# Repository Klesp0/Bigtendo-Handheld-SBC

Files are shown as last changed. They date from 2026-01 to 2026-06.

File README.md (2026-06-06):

# Bigtendo Handheld SBC

A portable gaming console built from scratch around a Raspberry Pi 5 and an Adafruit Feather RP2040. It runs RetroPie for retro game emulation and original games written in Pygame and Godot, all controlled with analog joysticks and physical buttons through a custom USB-HID gamepad interface. The whole thing lives inside a 3D-printed two-part enclosure designed in Fusion 360.

The console combines a Raspberry Pi 5 running RetroPie with a separate microcontroller (Feather RP2040) that handles all gamepad input. The RP2040 reads two analog joysticks and 17 physical buttons, applies calibration and deadzone logic, and presents itself to the Pi as a standard USB-HID gamepad, meaning every piece of software on the Pi (EmulationStation, RetroArch, pygame, Godot) sees it as a normal controller with zero extra configuration.

Audio goes through an I2S DAC (Adafruit PCM5122) into a PAM8403 Class D stereo amplifier driving two small cavity speakers. Power comes from a Suptronics X1201 UPS HAT with dual 18650 Li-Ion cells.

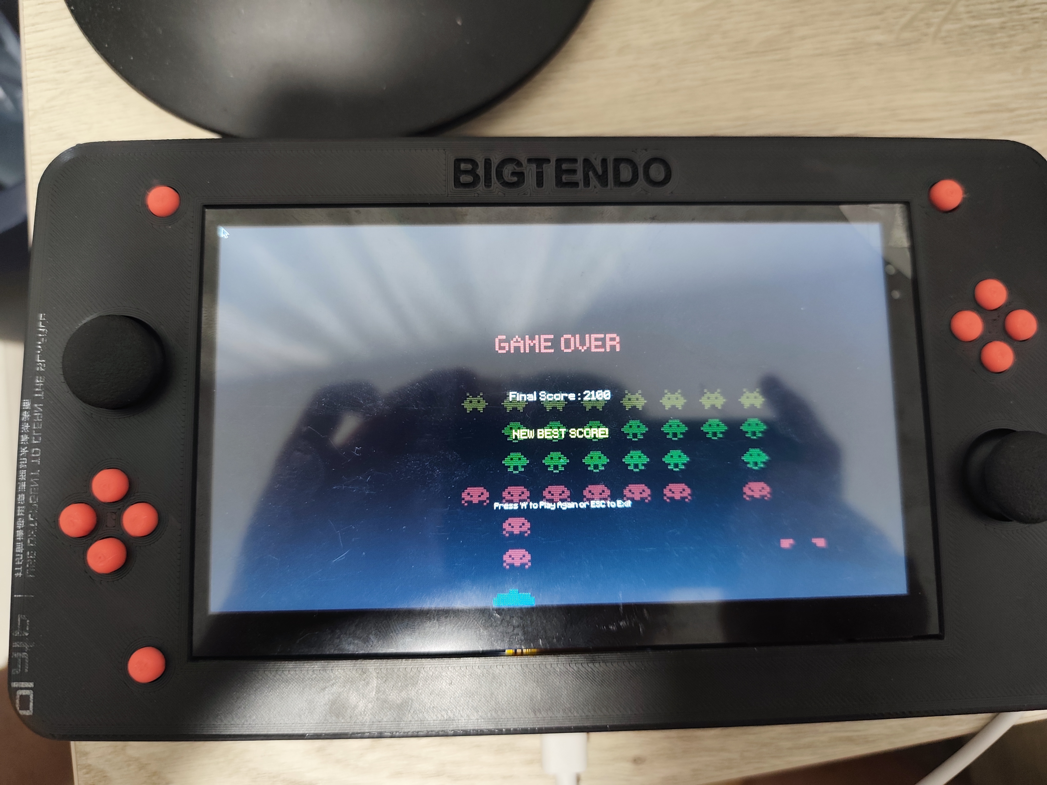
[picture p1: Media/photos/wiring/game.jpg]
Bigtendo Console


---

### Why We Built It

We wanted to understand how a real consumer device works, from the PCB-level electronics to the operating system configuration and to the mechanical design. Buying a kit or following a tutorial wouldn't teach us that. Every part of this console forced us to learn something new: I2S audio protocols, USB-HID protocol, device tree overlays, 3D printing tolerances, soldering, and a lot of debugging.

We are currently designing a custom PCB to combine the audio DAC, amplifier, controller logic, and battery management onto a single board, replacing both the perfboard wiring and the UPS HAT, significantly reducing the internal complexity, size and making the whole build cheaper than buying a standalone UPS module.

### How to Use It

The console boots directly into EmulationStation, RetroPie's game browser. Use the D-pad and A/B buttons to navigate and launch games. Retro games run through RetroArch emulators, and our custom pygame and Godot titles launch the same way through the Ports section, everything is accessible from one menu. The gamepad shows up as a standard USB controller, so it also works if you plug the Feather into any PC. Pick it up to play some games, or use it as a hands-on platform for learning embedded systems, hardware design, Linux configuration, and game development.

---

## Photos

| | |
|:---:|:---:|
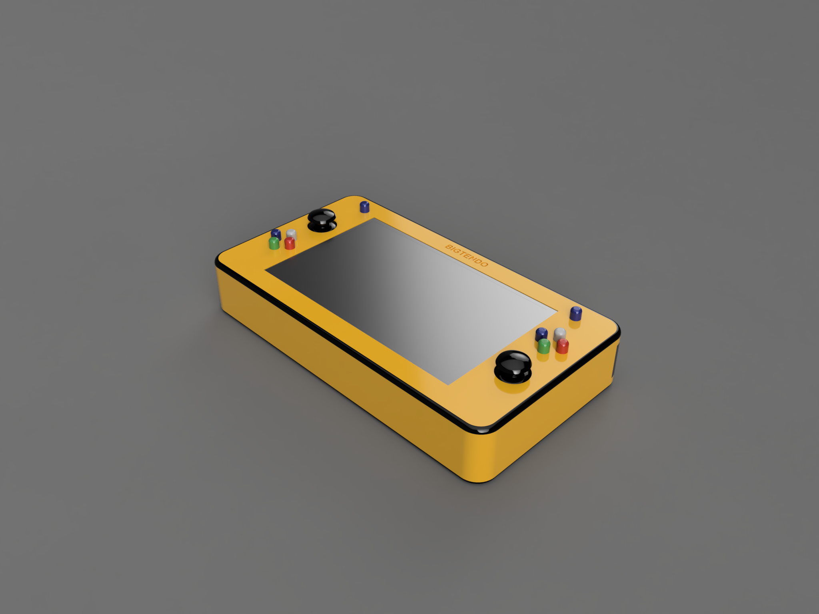
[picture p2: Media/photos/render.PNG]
render
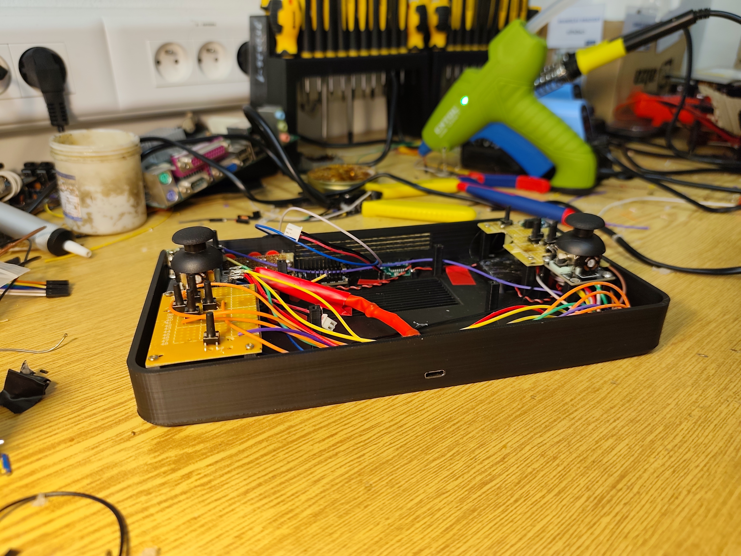
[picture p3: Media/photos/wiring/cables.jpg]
cables
|  |  |
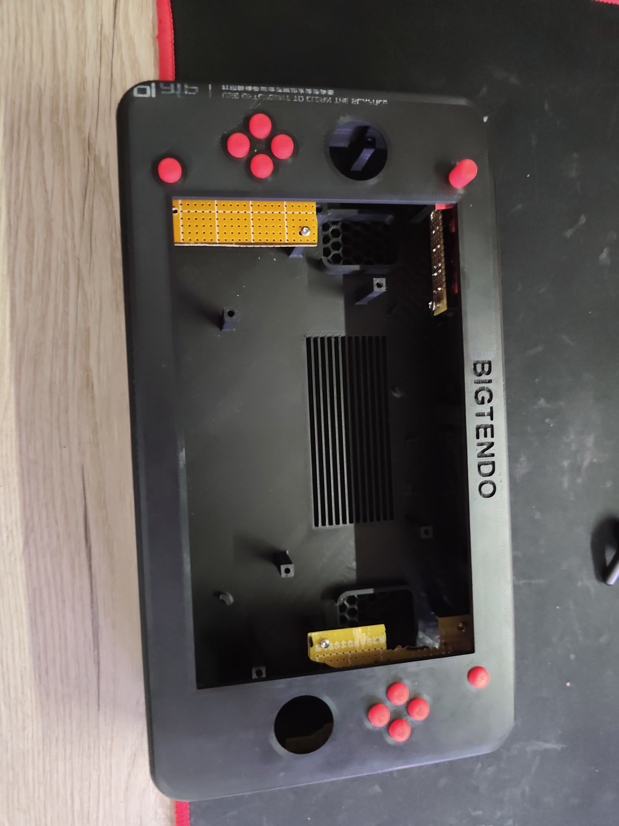
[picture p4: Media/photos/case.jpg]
top
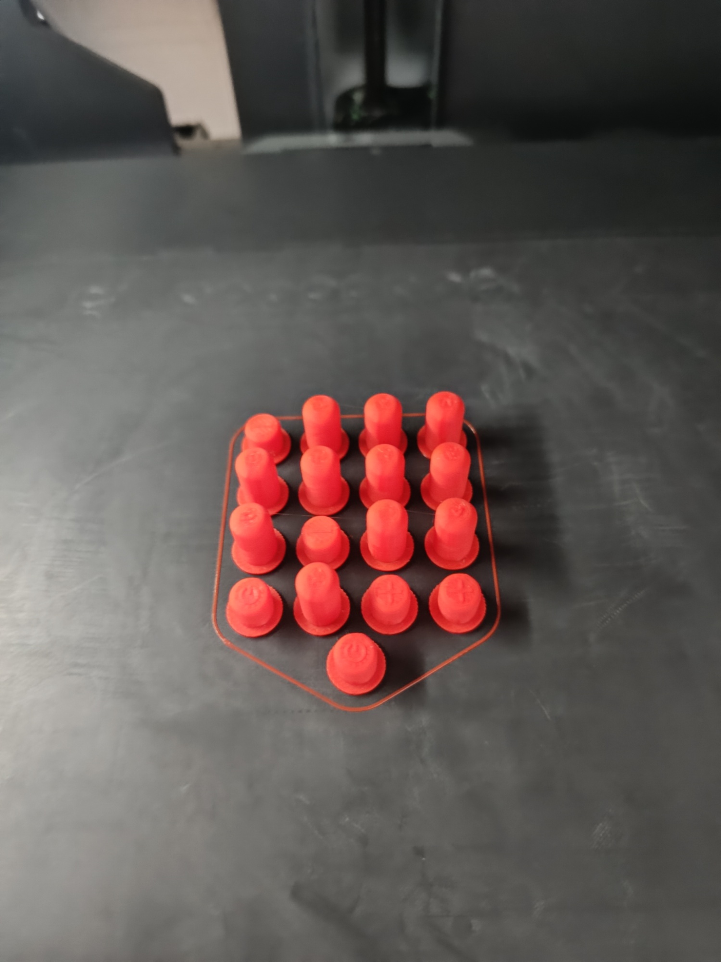
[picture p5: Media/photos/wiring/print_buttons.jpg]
buttons
|  |  |
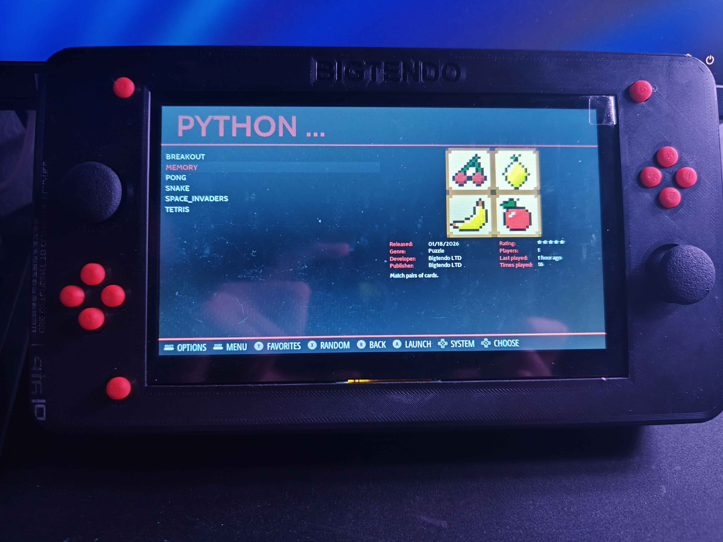
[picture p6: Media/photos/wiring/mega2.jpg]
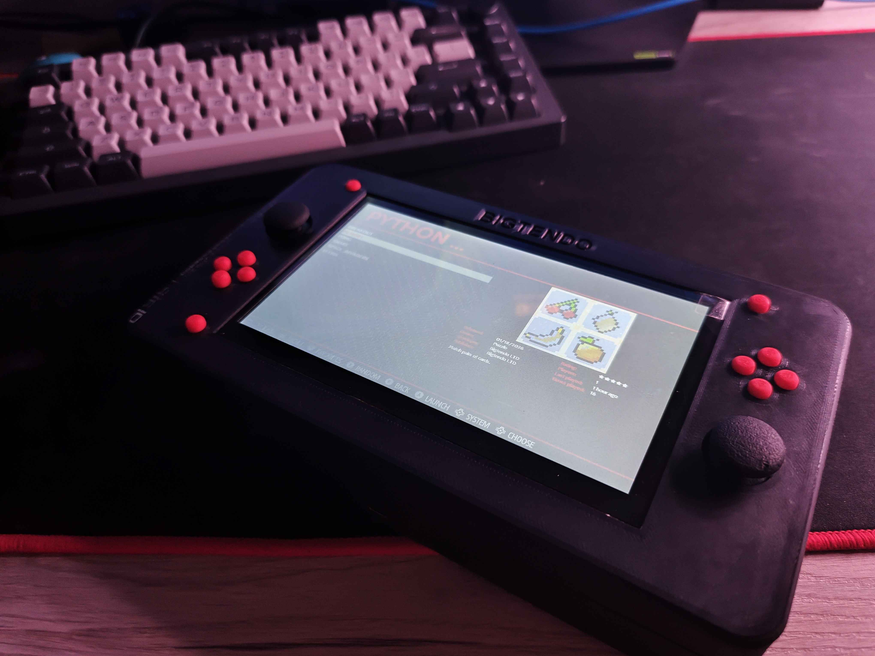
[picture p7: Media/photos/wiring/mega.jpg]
|  |  |

---

## Hardware

| Component | Details |
|---|---|
| **Compute** | Raspberry Pi 5 (8GB RAM), RetroPie OS |
| **Controller** | Adafruit Feather RP2040, USB-HID gamepad with auto-calibration, deadzone, axis inversion/swap |
| **Inputs** | 2x analog joysticks, 17x tactile buttons (D-pad, A/B/X/Y, Start/Select/Home, shoulders) |
| **Audio** | Adafruit PCM5122 I2S DAC, PAM8403 Class D amp, 2x 2030 cavity speakers (8 ohm, 2W) |
| **Power** | Suptronics X1201 UPS HAT + 2x 18650 Li-Ion cells |
| **Display** | 7" HDMI touchscreen (1024x600) |
| **Enclosure** | 3D-printed PLA, ~245 x 135 x 45mm, Bambu Lab X1 Carbon |

---

## Repository Structure

Each folder has its own README with more detail.

```
├── Design/          ← CAD models (.f3d, .step, .stl), assets (icons, sprites, sounds)
├── Firmware/        ← Feather RP2040 CircuitPython controller firmware
├── Games/           ← Pygame and Godot titles
├── Docs/            ← Build guide, wiring guide, pin mapping
├── Media/           ← Build photos and screenshots
├── BOM.csv          ← Bill of materials with purchase links
└── README.md        ← You are here
```

---

## How to Build

Full instructions in **[Docs/build_guide.md](Docs/build_guide)** and **[Docs/wiring_guide.md](Docs/wiring_guide)**. Print the case, flash the Feather, wire everything, configure the Pi, assemble, and play.

---

## Built By

- **[@Klesp0](https://github.com/Klesp0)** - Hardware, CAD, electronics, firmware, audio, assembly
- **[@lukas513](https://github.com/lukas513)** - Games (Pygame and Godot), co-designed enclosure
- **[@A-Kosec](https://github.com/A-Kosec)** - Pygame games, game design, visual assets, configuring retropie

---

## License

[GNU General Public License v3.0](LICENSE)

---

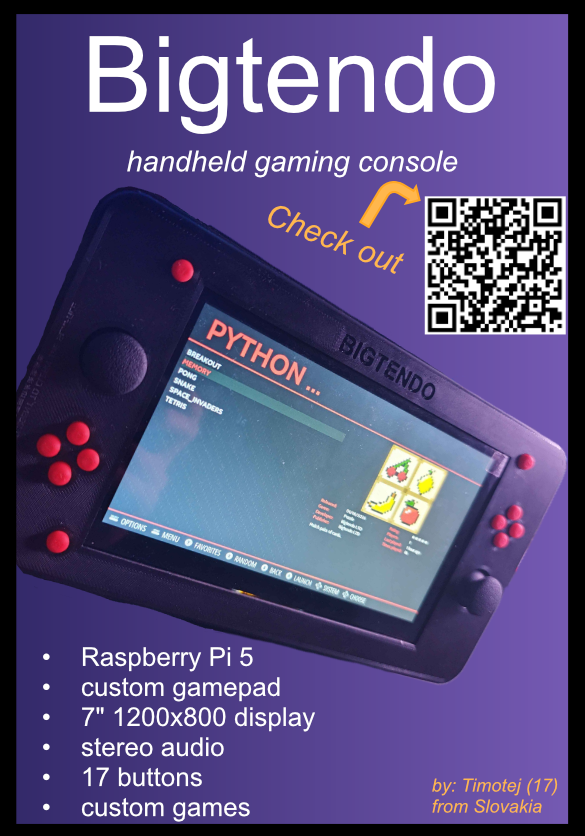
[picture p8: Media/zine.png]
zine


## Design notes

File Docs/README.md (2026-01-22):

# Documentation

Documentation for the Bigtendo handheld SBC console.

* **build-guide/** - Build guide with photos
* **wiring-guide/** - Wiring instructions
* **PCB\_schematics/** - Design files for the upcoming integrated V2 board

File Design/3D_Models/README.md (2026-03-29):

.f3z - original Fusion files

.3mf - files for printing. If you have bambulab you can just change your 3d printer and print with my settings.

.step -  neutral 3d file

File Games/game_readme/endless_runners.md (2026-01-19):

# 🏃 Endless Runner

## Overview
Chrome Dino-style endless runner with desert theme. Jump and slide to avoid obstacles while running at increasing speed.

## Gameplay
- **Objective**: Run as far as possible without hitting obstacles
- **Controls**: 
  - **SPACE / A button**: Jump
  - **DOWN / Crouch button**: Slide
- **Scoring**: Distance traveled (meters)
- **Difficulty**: Speed increases over time

## Features
- ✅ Procedural obstacle generation
- ✅ Running, jumping, sliding animations
- ✅ Parallax scrolling background
- ✅ Collectible coins
- ✅ Power-ups (magnet, shield)
- ✅ Day/night cycle
- ✅ High score tracking

## Technical Details
- **Languages**: GDScript
- **Scenes**: 
  - Main.tscn (game world)
  - Player.gd (character controller)
  - ObstacleSpawner.gd (procedural generation)

## Assets Required
- Player sprites: run (4 frames), jump, slide
- Obstacles: cactus (3 variants), bird, rock
- Backgrounds: sky, mountains (2 layers), ground
- Collectibles: coin (3 frame animation)
- Power-ups: magnet, shield icons

## Development Time
**Estimated**: 4-5 hours
- Player movement: 1h
- Obstacle spawning: 1.5h
- Collision detection: 1h
- UI & polish: 1.5h

## Testing Checklist
- [ ] Jump feels responsive
- [ ] Slide animation works
- [ ] Obstacles spawn at correct intervals
- [ ] Collision detection accurate
- [ ] Score increments properly
- [ ] Game over screen shows
- [ ] High score saves

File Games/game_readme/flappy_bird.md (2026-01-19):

# 🐦 Flappy Bird

## Overview
Classic Flappy Bird clone with pixel art style. Tap to flap through pipes.

## Gameplay
- **Objective**: Pass through as many pipes as possible
- **Controls**: 
  - **SPACE / A button**: Flap wings
- **Scoring**: 1 point per pipe passed
- **Difficulty**: Fixed pipe speed, tight gaps

## Features
- ✅ Simple one-button control
- ✅ Smooth gravity physics
- ✅ Procedural pipe generation
- ✅ Parallax clouds
- ✅ Wing flapping animation
- ✅ Medal system (bronze/silver/gold)
- ✅ High score

## Technical Details
- **Engine**: Godot 4.3
- **Physics**: Custom gravity (980 units/s²)
- **Key Scripts**:
  - Bird.gd (physics + animation)
  - Pipe.gd (scrolling + collision)
  - GameManager.gd (scoring + game state)

## Assets Required
- Bird: 3 frame flapping animation
- Pipes: top and bottom segments
- Background: sky gradient, clouds, ground
- UI: medal icons, game over screen

## Development Time
**Estimated**: 4-5 hours
- Bird physics: 1h
- Pipe spawning: 1.5h
- Collision: 1h
- UI & polish: 1.5h

## Difficulty Tuning
```gdscript
const GRAVITY = 980.0        # Adjust for difficulty
const JUMP_VELOCITY = -600.0 # Lower = harder
const PIPE_SPEED = 200.0     # Higher = harder
const PIPE_GAP = 200.0       # Smaller = harder
```

## Testing Checklist
- [ ] Bird flaps on input
- [ ] Gravity feels natural
- [ ] Pipes scroll smoothly
- [ ] Gap size is fair
- [ ] Collision detection accurate
- [ ] Score increments correctly
- [ ] Game over works
- [ ] Restart works

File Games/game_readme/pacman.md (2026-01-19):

# 👻 Pac-Man

## Overview
Classic Pac-Man maze game with 4 ghosts (Blinky, Pinky, Inky, Clyde). Eat pellets, avoid ghosts, use power-ups.

## Gameplay
- **Objective**: Eat all pellets without getting caught by ghosts
- **Controls**: 
  - **Arrow keys / D-Pad**: Move Pac-Man
- **Scoring**: 
  - Small pellet: 10 points
  - Power pellet: 50 points
  - Ghost: 200/400/800/1600 points (combo)
  - Fruit: 100-1000 points
- **Lives**: 3

## Features
- ✅ Classic maze layout
- ✅ 4 ghosts with unique AI
- ✅ Power pellets (eat ghosts)
- ✅ Fruit bonus items
- ✅ Ghost house behavior
- ✅ Scatter/Chase mode switching
- ✅ Warp tunnels
- ✅ Death/respawn animation
- ✅ Level progression

## Technical Details
- **Engine**: Godot 4.3
- **Grid-based movement**: 32x32 tiles
- **AI Algorithms**:
  - **Blinky**: Chases Pac-Man directly
  - **Pinky**: Targets 4 tiles ahead of Pac-Man
  - **Inky**: Uses Blinky's position + Pac-Man
  - **Clyde**: Chases until close, then scatters
- **Pathfinding**: BFS (Breadth-First Search)

## Ghost AI States
1. **Scatter**: Each ghost targets corner
2. **Chase**: Hunt Pac-Man with unique strategy
3. **Frightened**: Run away (after power pellet)
4. **Eyes**: Return to ghost house after eaten

## Assets Required
- Pac-Man: 8 directional sprites, death animation
- Ghosts: 4 colors x 4 directions, frightened state, eyes
- Maze: tileset for walls, pellets, power pellets
- Fruit: cherry, strawberry, orange, apple
- UI: lives indicator, score, ready text

## Development Time
**Estimated**: 7-9 hours
- Maze & movement: 2h
- Ghost AI (basic): 3h
- Ghost AI (advanced): 2h
- Power pellets & scoring: 1h
- UI & polish: 1h

## Testing Checklist
- [ ] Pac-Man moves in 4 directions
- [ ] Can't move through walls
- [ ] Eats pellets correctly
- [ ] Ghosts chase properly
- [ ] Power pellets work
- [ ] Eating ghosts gives points
- [ ] Warp tunnels work
- [ ] Level completes when all pellets eaten
- [ ] Lives system works
- [ ] Game over at 0 lives

## Known Issues
- Ghost AI can get stuck in corners (workaround: add random scatter)

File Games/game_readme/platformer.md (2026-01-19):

# 🎮 Platformer

## Overview
2D platformer inspired by Super Mario. Jump, run, collect coins, defeat enemies, reach the flag.

## Gameplay
- **Objective**: Reach the end flag
- **Controls**: 
  - **Arrow keys / D-Pad**: Move left/right
  - **SPACE / A button**: Jump
  - **DOWN**: Crouch
- **Mechanics**:
  - Double jump
  - Wall jump
  - Ground pound
  - Enemy stomp
- **Collectibles**: Coins, gems, keys
- **Lives**: 3 (get more at 100 coins)

## Features
- ✅ Physics-based movement
- ✅ Multiple enemy types
- ✅ Destructible blocks
- ✅ Moving platforms
- ✅ Checkpoints
- ✅ Secret areas
- ✅ Boss fight (optional)
- ✅ 3-5 levels

## Technical Details
- **Engine**: Godot 4.3
- **Tilemap**: 32x32 grid
- **Physics**: Godot's built-in CharacterBody2D
- **Key Scripts**:
  - Player.gd (movement, jumps, attacks)
  - Enemy.gd (patrol, chase AI)
  - MovingPlatform.gd (path following)
  - Checkpoint.gd (save progress)

## Player Abilities
```gdscript
const SPEED = 200.0
const JUMP_VELOCITY = -500.0
const DOUBLE_JUMP_VELOCITY = -400.0
const GRAVITY = 980.0
const WALL_SLIDE_SPEED = 50.0
```

## Enemy Types
- **Slime**: Patrols back and forth
- **Flying**: Sine wave pattern
- **Spikes**: Stationary hazard
- **Boss**: Multi-phase fight (if time permits)

## Assets Required
- Player: idle, walk (4 frames), run (4 frames), jump, fall, crouch, hurt, death
- Enemies: slime (2 frames), fly (2 frames), spike
- Tiles: ground, platforms, walls, spikes, coins, gems, key, door, flag
- Backgrounds: sky, clouds, mountains, trees
- Effects: jump dust, landing dust, hit effect

## Development Time
**Estimated**: 6-8 hours
- Player movement: 2h
- Tilemap & level design: 2h
- Enemy AI: 2h
- Collectibles & checkpoints: 1h
- Polish & sound: 1h

## Level Design Tips
- Start easy, increase difficulty gradually
- Teach mechanics before requiring them
- Place checkpoints after difficult sections
- Hide secrets off the main path
- Add visual hints (coins leading to platforms)

## Testing Checklist
- [ ] Jump feels good (height, gravity)
- [ ] Wall jump works
- [ ] Double jump works
- [ ] Enemy collisions work
- [ ] Stomp kills enemies
- [ ] Touching enemy hurts player
- [ ] Coins collected properly
- [ ] Checkpoints save progress
- [ ] Death respawns at checkpoint
- [ ] Can reach flag

## Known Issues
- Player can get stuck in walls if moving too fast (add collision buffer)

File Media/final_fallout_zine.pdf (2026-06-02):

# Bigtendo

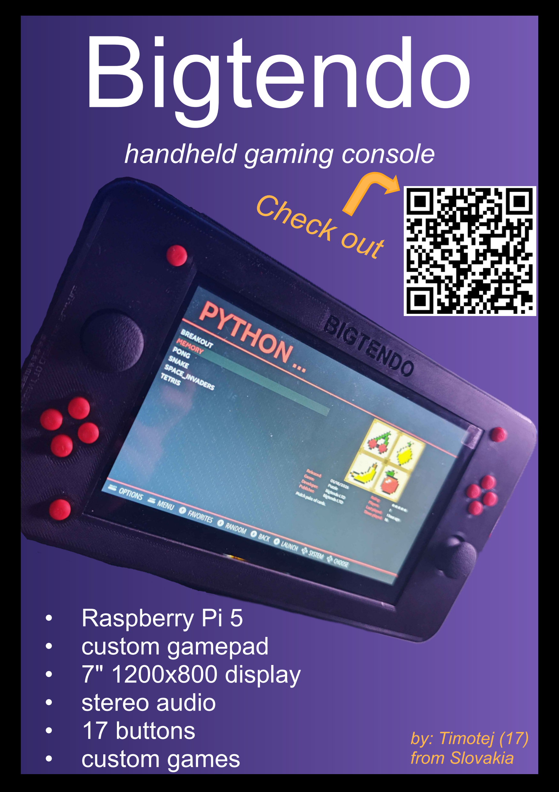
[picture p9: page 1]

## Check out

- Raspberry Pi 5
- custom gamepad
- 7" 1200x800 display
- stereo audio
- 17 buttons
- custom games

by: Timotej (17)
from Slovakia

handheld gaming console

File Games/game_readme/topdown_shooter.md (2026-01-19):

# 🔫 Top-Down Shooter

## Overview
Hotline Miami-style top-down shooter. Aim with mouse/joystick, shoot enemies, clear rooms.

## Gameplay
- **Objective**: Clear all enemies in each room
- **Controls**: 
  - **Arrow keys / Left stick**: Move (8-way)
  - **Mouse / Right stick**: Aim
  - **SPACE / A button**: Shoot
  - **R**: Reload
- **Weapons**: Pistol, Rifle, Shotgun
- **Health**: 100 HP
- **Scoring**: Kills, accuracy, time bonus

## Features
- ✅ 8-way movement
- ✅ Mouse/joystick aiming
- ✅ 3 weapon types
- ✅ Enemy AI (patrol, chase, shoot)
- ✅ Line of sight system
- ✅ Destructible objects
- ✅ Multiple rooms/levels
- ✅ Ammo management
- ✅ Health pickups
- ✅ Blood effects

## Technical Details
- **Engine**: Godot 4.3
- **View**: Top-down orthogonal
- **Key Scripts**:
  - Player.gd (movement, aiming, shooting)
  - Enemy.gd (AI state machine)
  - Weapon.gd (fire rate, damage, ammo)
  - Bullet.gd (projectile physics)

## Weapon Stats
```gdscript
# Pistol
damage = 20
fire_rate = 0.3
ammo_capacity = 12
reload_time = 1.5

# Rifle
damage = 15
fire_rate = 0.1
ammo_capacity = 30
reload_time = 2.0

# Shotgun
damage = 10 (x6 pellets)
fire_rate = 0.8
ammo_capacity = 6
reload_time = 2.5
```

## Enemy AI States
1. **Patrol**: Walk along waypoints
2. **Alert**: Player spotted, move to last seen position
3. **Chase**: Follow player
4. **Attack**: Stop and shoot at player
5. **Cover**: Hide behind obstacles when low health

## Assets Required
- Player: idle (4 directions), walk (4 directions x 2 frames)
- Enemies: soldier, robot, turret
- Weapons: pistol, rifle, shotgun sprites
- Bullets: small projectile, muzzle flash
- Environment: walls, crates, doors, barrels
- Effects: blood splatter, explosion, smoke
- UI: health bar, ammo counter, crosshair

## Development Time
**Estimated**: 8-10 hours
- Player controller: 2h
- Enemy AI: 3h
- Weapons & shooting: 2h
- Level design: 2h
- Polish: 1h

## Level Design
- Start with tutorial room (1 enemy)
- Gradually increase enemy count
- Mix enemy types for variety
- Place cover strategically
- Add health/ammo pickups after tough fights

## Testing Checklist
- [ ] Mouse aiming smooth
- [ ] Joystick aiming works
- [ ] Shooting feels responsive
- [ ] Enemies chase properly
- [ ] Line of sight works
- [ ] Cover system works
- [ ] Ammo system works
- [ ] Reload works
- [ ] Health system works
- [ ] Death/respawn works

## Known Issues
- AI can get stuck on corners (add navigation mesh)

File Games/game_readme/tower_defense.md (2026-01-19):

# 🗼 Tower Defense

## Overview
Classic tower defense. Build towers, upgrade them, stop enemy waves from reaching your base.

## Gameplay
- **Objective**: Survive all waves without losing all lives
- **Controls**: 
  - **Mouse / D-Pad**: Select tower, place on map
  - **Click tower**: Upgrade or sell
- **Resources**: 
  - **Money**: Build/upgrade towers
  - **Lives**: Lose when enemies reach end
- **Towers**: Basic, Cannon, Laser, Ice
- **Enemies**: Basic, Fast, Tank, Flying

## Features
- ✅ 4 tower types (3 upgrade levels each)
- ✅ 4 enemy types
- ✅ Path-based enemy movement
- ✅ Tower range indicators
- ✅ Upgrade system
- ✅ Sell towers (50% refund)
- ✅ 10-15 waves
- ✅ Speed up button (2x)
- ✅ Pause menu

## Technical Details
- **Engine**: Godot 4.3
- **Pathfinding**: Predefined path (not A*)
- **Key Scripts**:
  - Tower.gd (targeting, shooting, upgrading)
  - Enemy.gd (path following, health)
  - WaveManager.gd (spawn timing, difficulty scaling)
  - GameManager.gd (money, lives, win/lose)

## Tower Stats

### Basic Tower
- **Cost**: 100
- **Damage**: 10 → 20 → 30
- **Fire Rate**: 1.0s → 0.8s → 0.6s
- **Range**: 150 → 170 → 200

### Cannon Tower
- **Cost**: 200
- **Damage**: 50 → 80 → 120 (AOE)
- **Fire Rate**: 2.0s → 1.5s → 1.0s
- **Range**: 180 → 200 → 220

### Laser Tower
- **Cost**: 250
- **Damage**: 5 (continuous)
- **Fire Rate**: 0.1s
- **Range**: 200 → 220 → 250

### Ice Tower
- **Cost**: 150
- **Damage**: 5 → 10 → 15
- **Slow**: 50% → 60% → 70%
- **Range**: 120 → 140 → 160

## Enemy Types
- **Basic**: 100 HP, 50 speed, 10 reward
- **Fast**: 60 HP, 100 speed, 15 reward
- **Tank**: 300 HP, 30 speed, 30 reward
- **Flying**: 80 HP, 70 speed, 20 reward (immune to ground towers)

## Wave Scaling
```gdscript
func calculate_wave_difficulty(wave_num):
    enemy_count = 5 + wave_num * 2
    enemy_health_multiplier = 1.0 + wave_num * 0.1
    enemy_speed_multiplier = 1.0 + wave_num * 0.05
```

## Assets Required
- Towers: 4 types x 3 levels = 12 sprites
- Tower projectiles: bullet, cannonball, laser beam, ice shard
- Enemies: 4 types x 2 frames = 8 sprites
- Map tiles: grass, path
- UI: tower menu, upgrade panel, money/lives display
- Effects: explosion (3 frames), ice effect

## Development Time
**Estimated**: 10-12 hours
- Tower system: 3h
- Enemy pathfinding: 2h
- Wave manager: 2h
- Upgrade system: 2h
- UI & map: 2h
- Balancing: 1h

## Balancing Tips
- Early waves should be easy (teach mechanics)
- Introduce 1 new enemy type every 3 waves
- Boss waves at 5, 10, 15
- Money rewards should allow 1 tower per wave
- Player should need 3-4 upgraded towers to win

## Testing Checklist
- [ ] Towers place correctly
- [ ] Range indicators show
- [ ] Towers shoot enemies in range
- [ ] Targeting works (closest, strongest, etc.)
- [ ] Upgrades apply correctly
- [ ] Selling works
- [ ] Enemies follow path
- [ ] Money system works
- [ ] Lives decrease when enemy reaches end
- [ ] All waves completable
- [ ] Win condition works
- [ ] Lose condition works

## Known Issues
- Towers can shoot through obstacles (add line-of-sight check)

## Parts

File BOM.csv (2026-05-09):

Component | Qty | Unit Price (EUR) | Total (EUR) | Supplier | Link | Total (EUR) | 296.46
Raspberry Pi 5 - 8GB RAM | 1 | 128.96 | 128.96 | RPishop.cz | https://rpishop.cz/raspberry-pi-5/6498-raspberry-pi-5-8gb-ram.html
Suptronics X1201 UPS Shield for RPi 5 | 1 | 39.45 | 39.45 | RPishop.cz | https://rpishop.cz/523690/suptronics-x1201-ups-shield-pro-raspberry-pi-5/
PremiumCord Flexi HDMI Typ A (F) - micro HDMI Typ D (M) adapter | 1 | 3.66 | 3.66 | RPishop.cz | https://rpishop.cz/499888/premiumcord-flexi-adapter-hdmi-typ-a-samice-micro-hdmi-typ-d-samec-pro-ohebne-zapojeni/
Waveshare DIY HDMI flat cable 0.1m | 1 | 2.02 | 2.02 | RPishop.cz | https://rpishop.cz/diy-hdmi/3012-diy-hdmi-plochy-kabel-10-cm.html
HDMI connector for DIY cable - right angle (up) male | 1 | 5.31 | 5.31 | RPishop.cz | https://rpishop.cz/diy-hdmi/3017-hdmi-koncovka-pro-diy-hdmi-kabel-pravy-uhel-prava-samec.html
micro HDMI connector for DIY cable - right angle (up) | 1 | 5.31 | 5.31 | RPishop.cz | https://rpishop.cz/diy-hdmi/2855-adafruit-micro-hdmi-adapter-pro-diy-hdmi-kabel-pravouhly-konektor-pravy-ohyb.html
7 inch 1024x600 TFT display for RPi HDMI touch | 1 | 43.00 | 43.00 | LaskaKit | https://www.laskakit.cz/en/7--1024x600-tft-displej-pro-raspberry-pi--hdmi--dotykovy/
Raspberry Pi 5 Active Cooler | 1 | 6.15 | 6.15 | Elecom.sk | https://www.elecom.sk/raspberry-pi-5-active-cooler-2/
Adafruit Feather RP2040 | 1 | 15.50 | 15.50 | Elecom.sk | https://www.elecom.sk/adafruit-feather-rp2040/
Adafruit PCM5122 I2S DAC with Line Level Output | 1 | 10.60 | 10.60 | Elecom.sk | https://www.elecom.sk/adafruit-pcm5122-i2s-dac-with-line-level-output-hw--i2c-or-spi/
2030 Cavity Speaker 8Ohm 2W 2PIN PH1.25 | 2 | 2.23 | 4.46 | Elecom.sk | https://www.elecom.sk/2030-cavity-speaker-type-b--8-2w--high-quality-sound--compact-size--2pin-ph1-25-connector/
Kingston Canvas Select Plus microSDXC 128GB Class 10 UHS-I | 1 | 13.79 | 13.79 | Alza.sk | https://www.alza.sk/kingston-canvas-select-plus-micro-sdxc-128gb-class-10-uhs-i-sd-adapter-d5689872.htm
Perfboard 5cm x 7cm | 3 | 0.80 | 2.40 | Techfun.sk | https://techfun.sk/produkt/univerzalny-plosny-spoj-obojstranny/?attribute_pa_rozmery=5-cm-x-7-cm
PAM8403 stereo 2x3W mini amplifier | 1 | 0.65 | 0.65 | Techfun.sk | https://techfun.sk/produkt/pam8403-stereo-2x3w-mini-zosilnovac/
Tactile buttons 6x6x13mm (pack of 50) | 1 | 2.50 | 2.50 | Techfun.sk | https://techfun.sk/produkt/tlacidla-50-kusov-6x6x13-mm/
Tactile buttons 6x6x6mm (pack of 50) | 1 | 2.50 | 2.50 | Techfun.sk | https://techfun.sk/produkt/tlacidla-50-kusov-6x6x6-mm/
XH2.54 connector with cable 2P male+female | 3 | 0.40 | 1.20 | Techfun.sk | https://techfun.sk/produkt/konektor-s-kablikom-xh2-54-rozne-typy/
Joysticks | 2 | 0.75 | 1.50 | Techfun.sk | https://techfun.sk/produkt/joystick-2-osi-analogovy-vystup/
18650 battery EVE INR18650-26ME 2600mAh 15A | 2 | 3.75 | 7.50 | Techfun.sk | https://techfun.sk/produkt/18650-bateria-eve-inr18650-25p-2500mah-8c-20a/
Electrical tape | 1 | 0.80 | 0.80 | Techfun.sk | https://techfun.sk/produkt/izolacna-elektricka-paska-rozne-farby/
20cm Dupont wire 24awg | 1 | 0.50 | 0.50 | Techfun.sk | https://www.elecom.sk/male-to-male-dupont-line-40-pin-20-cm-24awg/
10cm Dupont wire 24awg | 1 | 1.45 | 1.45 | techfun.sk | https://techfun.sk/produkt/kabliky-40-kusov-10-cm-m-m/
10.9 grade M2-M5 screws kit | 1 | 8.00 | 8.00 | aliexpress | https://www.aliexpress.com/w/wholesale-screws-.html?spm=a2g0o.productlist.search.0

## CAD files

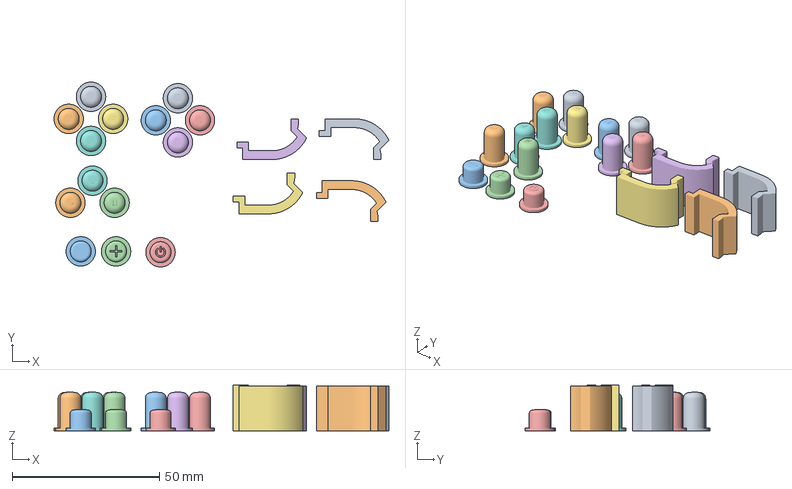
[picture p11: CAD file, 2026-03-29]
Design/3D_Models/.3mf_for_printing/buttons.3mf
113.8 x 62.8 x 15.5 mm
x (1) (1) (1)
x (1) (1)
x (1)
x

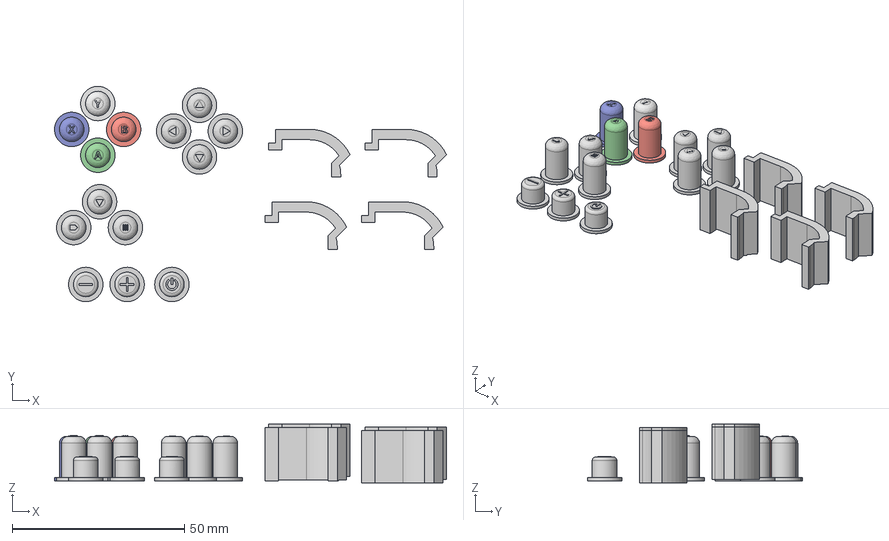
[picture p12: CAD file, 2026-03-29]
Design/3D_Models/.step/Buttons.step
113.8 x 62.5 x 17.0 mm
A, B, Y, X
D-pad
Right Shoulder Buttons x 2
Menu
Volume Down
Volume Up
Power

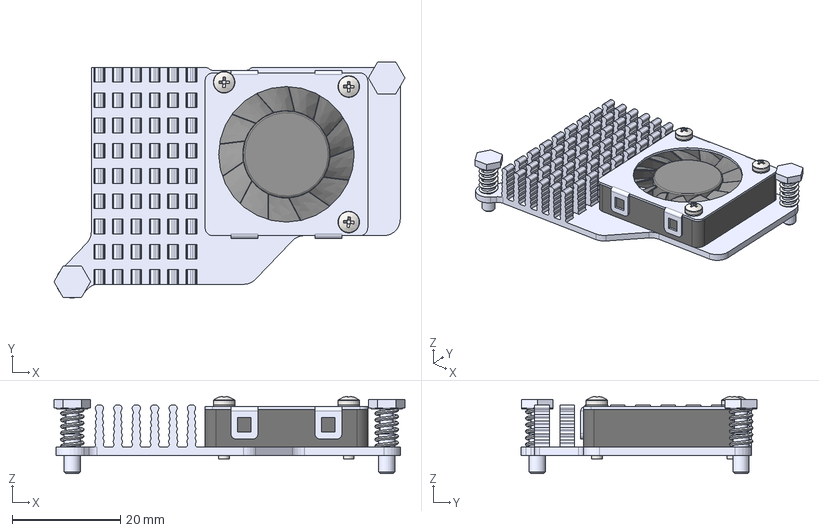
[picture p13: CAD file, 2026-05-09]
Design/3D_Models/component_models/Heatsink+fan RPi-5.step
64.8 x 43.5 x 14.2 mm
Heatsink-fan-base_RPi5
RotorBlades
MotorHouse
fan cover
Bolt_M3 PF x 2
Spring_M2,5 U x 2
pan head cross recess screw_din_DIN EN ISO 7045 - M2 x 10 - Z - 10N x 3
plain washer small grade a_din_Washer DIN 433 - 2 x 3

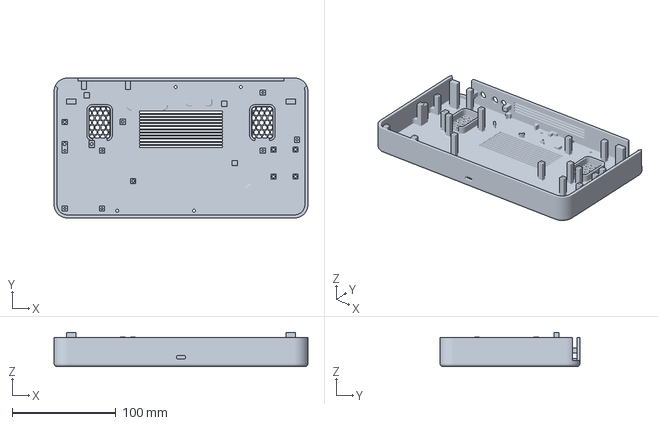
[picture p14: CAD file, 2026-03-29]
Design/3D_Models/.3mf_for_printing/case_lower.3mf
245.0 x 135.0 x 33.0 mm

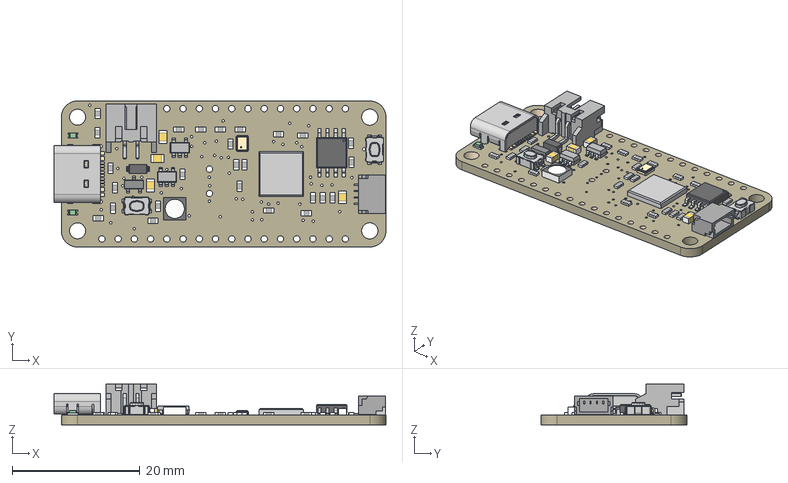
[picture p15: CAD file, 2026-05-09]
Design/3D_Models/component_models/4884 Feather RP2040.step
51.9 x 22.9 x 6.37 mm
Board
10uF x 4
ORANGE x 2
1K x 26
KMR2 x 2
AP2112-3.3
JSTPH
MCP73831T-2ACI/OT
WS2812B3535
2MB Flash
MBR540
DMG341
USB Type C
RP2040_QFN56
STEMMA_I2C_QT
12MHZ

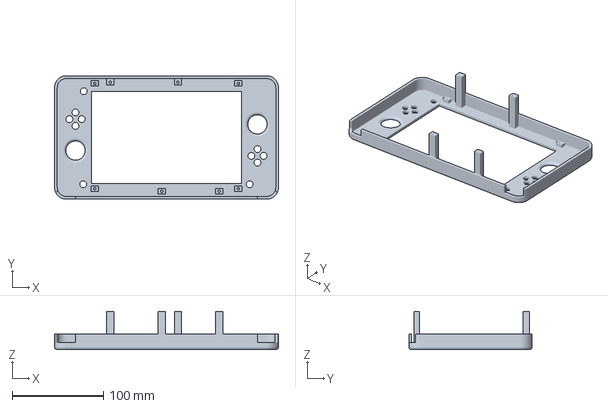
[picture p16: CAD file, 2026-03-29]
Design/3D_Models/.3mf_for_printing/case_upper.3mf
245.0 x 135.0 x 42.0 mm

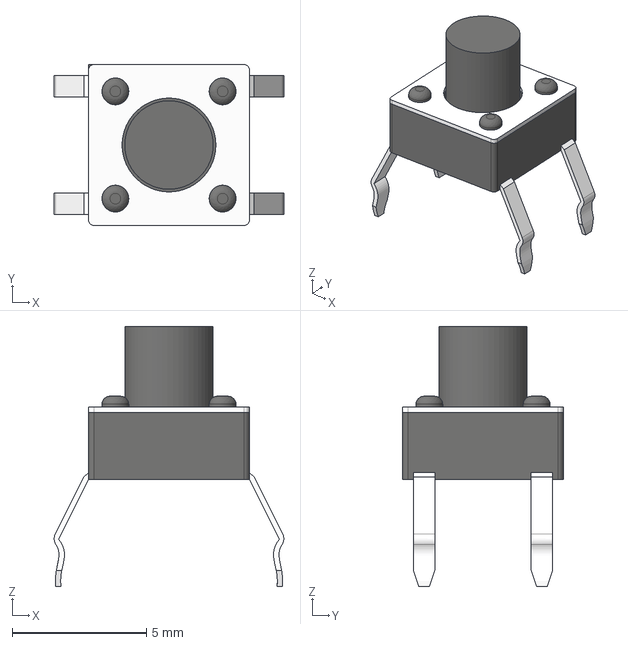
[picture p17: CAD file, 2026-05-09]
Design/3D_Models/component_models/Button 6x6-vyssie.step
8.57 x 6.00 x 9.70 mm

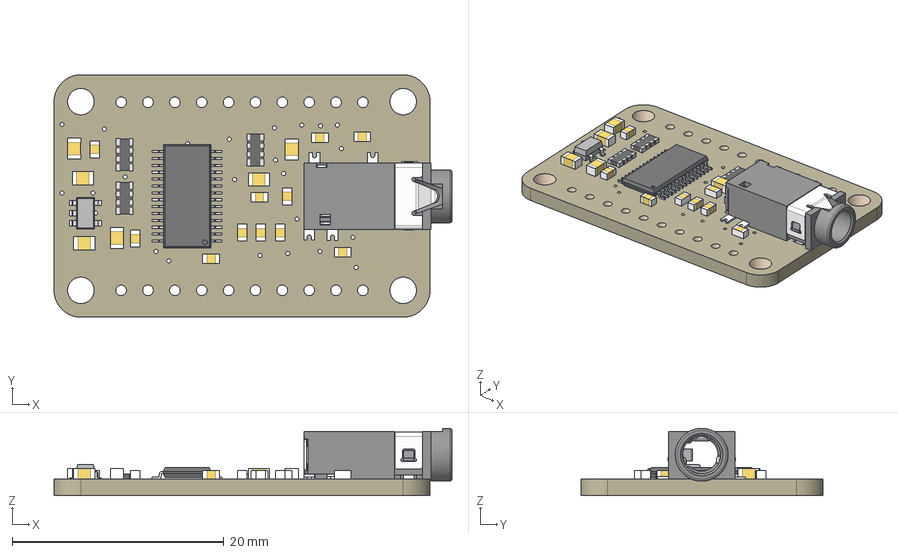
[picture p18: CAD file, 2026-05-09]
Design/3D_Models/component_models/Adafruit PCM5122 I2S DAC.step
37.6 x 22.9 x 6.37 mm
Board
2.2uF x 11
AP2127K-3.3
10uF x 6
TRRS_2SWITCH_PJ332A
PCM5122
10K x 3

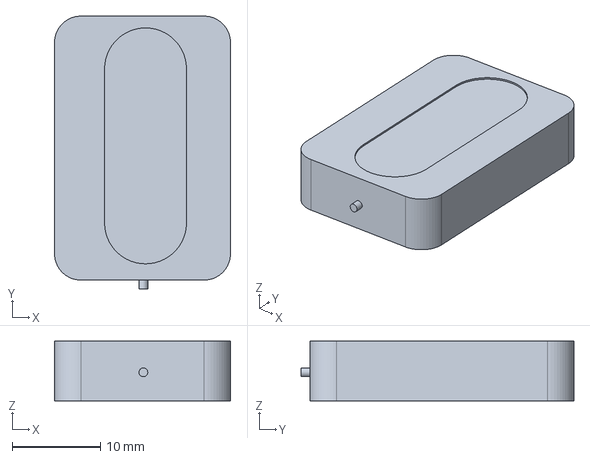
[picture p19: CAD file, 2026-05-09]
Design/3D_Models/component_models/speaker.step
20.0 x 31.0 x 6.80 mm

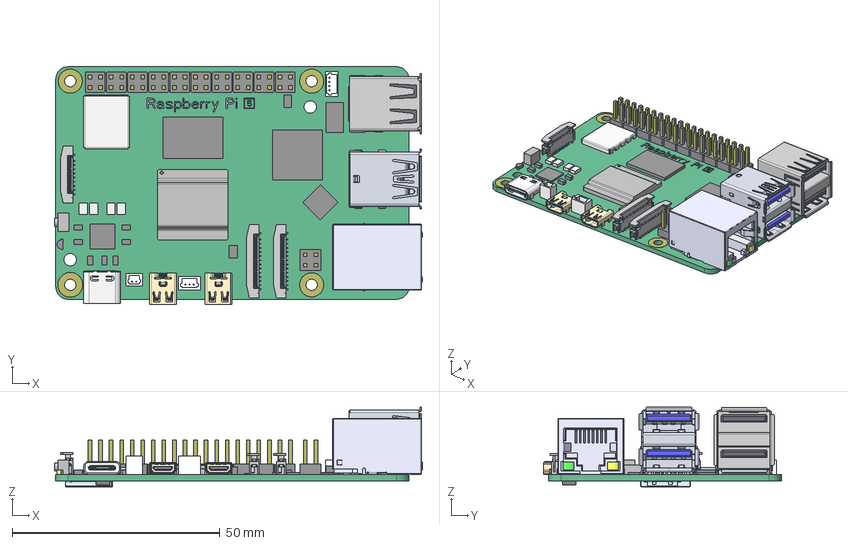
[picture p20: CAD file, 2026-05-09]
Design/3D_Models/component_models/raspberry_pi_5.step
88.5 x 57.2 x 19.2 mm
CONNECTOR
GPIO-HEADER
GROUND-1426
GROUND-1427
GROUND-1428
GROUND-1429
PCB
RAM
CPU
CHIP-1454
CHIP-1455
CHIP-1456
CHIP-1457
PMIC
POE_GEOMETRY
PWR-CONNECTOR
RP1
UART
XB-U224-08XN-1XR61
GIGABIT_ETHERNET_PORT__RPI4MODE
IMPORTED6-42380_1
IMPORTED9-52935_1
IMPORTED10-72927_1
IMPORTED7-187449_1
IMPORTED5-264500_1
IMPORTED3-272013_1
IMPORTED2-275127_1
N-396500_1
IMPORTED4-497392_1
IMPORTED8-498029_1
FEMALE_USB_TYPE_C_CONNECTOR__RP
FEMALE_MICRO_HDMI_CONNECTOR__RP x 2
2X_USB3_0_PORTS__RPI4MODELB_ANY
IR_1
CYPRESS_CYW43455_WIRELESS_MODUL
SWITCH-1559

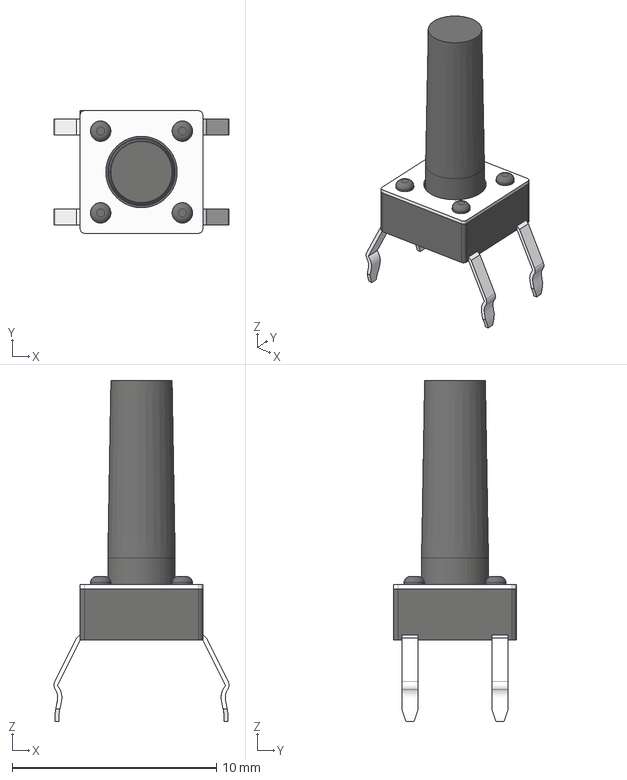
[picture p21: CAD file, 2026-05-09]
Design/3D_Models/component_models/Button 6x6x13.step
8.57 x 6.00 x 16.7 mm

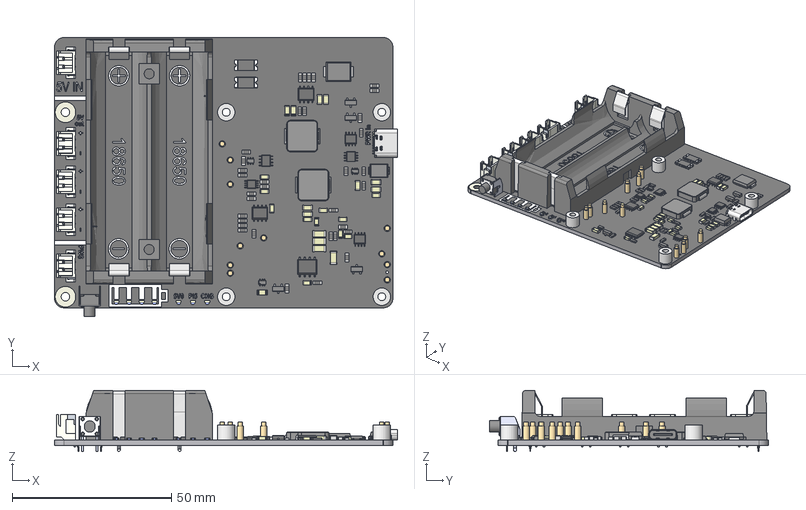
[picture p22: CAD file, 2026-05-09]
Design/3D_Models/component_models/Geekworm X1201 UPS Shield for RPi 5.step
107.8 x 87.7 x 19.3 mm
back side
front side
pads
PCB
pogo pin (20)
pogo pin (19)
pogo pin (18)
pogo pin (17)
pogo pin (16)
pogo pin (15)
pogo pin (14)
pogo pin (13)
pogo pin (12)
pogo pin (11)
pogo pin (10)
chip
chip_1
inductor (1)
inductor
fuse p lf (1)
fuse p lf
chip3 (2)
chip3 (1)
chip3
chip (2)
chip (1)
chip (1)_1
chip (1)_2
chip (1)_3
chip (2)_1
chip (1)_4
chip_2
resistor3 (5)
resistor3 (6)
resistor3 (6)_1
resistor3 (9)
resistor3 (8)
resistor3 (7)
resistor3 (17)
resistor3 (16)
resistor3 (19)
resistor3 (19)_1
resistor3 (18)
resistor3 (18)_1
resistor3 (17)_1
resistor3 (16)_1
resistor3 (15)
resistor3 (14)
resistor3 (16)_2
resistor3 (15)_1
resistor3 (14)_1
resistor3 (13)
resistor3 (12)
resistor3 (11)
resistor3 (10)
resistor3 (10)_1
resistor3 (9)_1
resistor3 (8)_1
resistor3 (7)_1
resistor3 (6)_2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

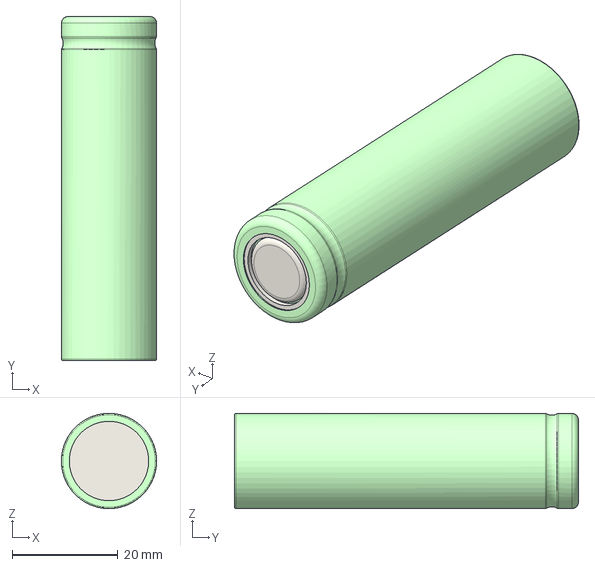
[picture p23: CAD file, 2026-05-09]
Design/3D_Models/component_models/Battery.step
18.0 x 65.0 x 18.0 mm

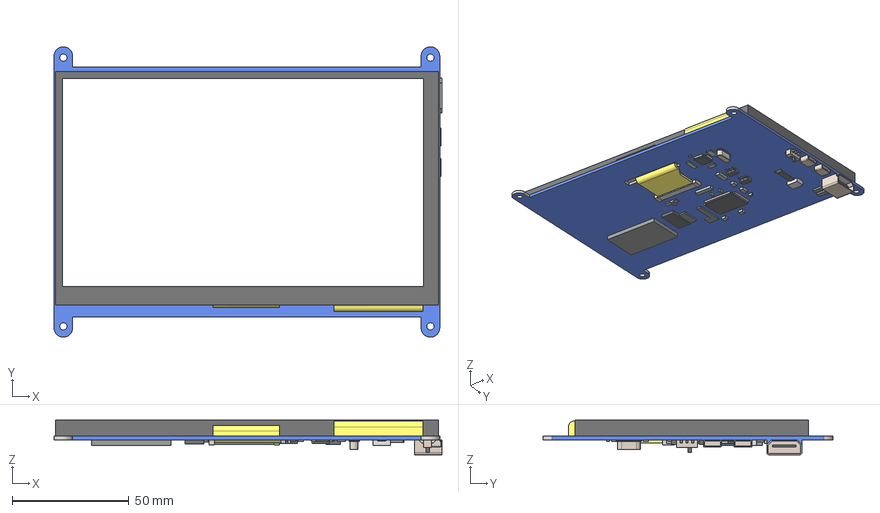
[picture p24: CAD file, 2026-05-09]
Design/3D_Models/component_models/display.step
166.1 x 124.3 x 14.9 mm

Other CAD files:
Design/3D_Models/.step/case_lower.step
Design/3D_Models/.step/case_upper.step
Design/3D_Models/component_models/amplfier PAM8403 3W.step
Design/3D_Models/component_models/USB Connector Type C female.STEP
Design/3D_Models/.f3z/Buttons.f3z
Design/3D_Models/.f3z/case_upper.f3z
Design/3D_Models/.stl/buttons.stl
Design/3D_Models/.stl/case_lower.stl
Design/3D_Models/.stl/case_upper.stl
Design/3D_Models/component_models/joystick.step

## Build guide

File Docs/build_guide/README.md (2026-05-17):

# Build Guide

Step-by-step instructions for building the Bigtendo console. Read the [Wiring Guide](Docs\wiring_guide\README.md) alongside this for detailed connection tables.

---

## Step 1 — Gather Parts

Everything you need is in [BOM.csv](BOM.csv) with purchase links. Before ordering, check component dimensions against the [CAD models](Design\3D_Models\component_models) - the enclosure was designed around specific display size.

---

## Step 2 — Print the Enclosure (Settings)

Download the [STL files](\Design\3D_Models\.stl).

>[!NOTE]
>If you have got a bambulab printer just import the [.3mf models](Design\3D_Models\.3mf_for_printing) into BambuStudio.

### Case settings
- **Print both case halves with the flat exterior face down.**

>[!NOTE]
>Upper part doesn't  need supports!

| Setting | Value |
|---|---|
| Material | PLA |
| Layer height | 0.08mm Extra Fine |
| Infill | 20% Gyroid |
| Walls loops | 4  |
| Supports (lower) | tree(auto) Threshold angle |
| Supports (lower) | Top Z distance 0.28mm |
| Bed | Textured PEI |
| Skirt loop (others)|  1 | 
| Print time (lower) | 9h42m |
| Print time (upper) | 4h31m  |
| Filament | 250g total |

### Button settings
- **Button caps print flat side down, no supports.**

| Setting | Value |
|---|---|
| Material | PLA |
| Layer height | 0.08mm Extra Fine |
| Infill | 40% Gyroid |
| Walls loops | 4  |
| Bed | Textured PEI |
| Skirt loop (others)|  1 | 
| Print time | 1h31m |
| Filament | 15g total |

| | |
|:---:|:---:|
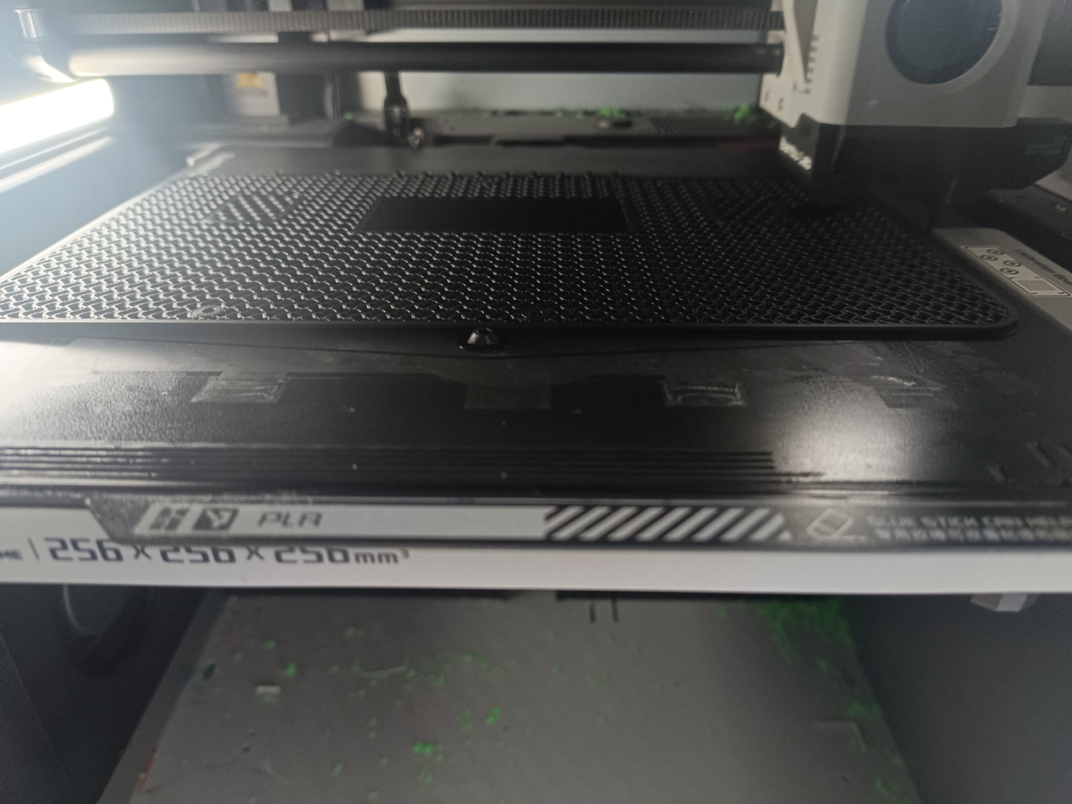
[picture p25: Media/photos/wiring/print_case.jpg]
case
|  | buttons |

---

## Step 3 — Flash the Feather RP2040

1. Download the CircuitPython `.uf2` for the Feather RP2040 from [circuitpython.org](https://circuitpython.org/board/adafruit_feather_rp2040/)
2. Plug the feather into your PC

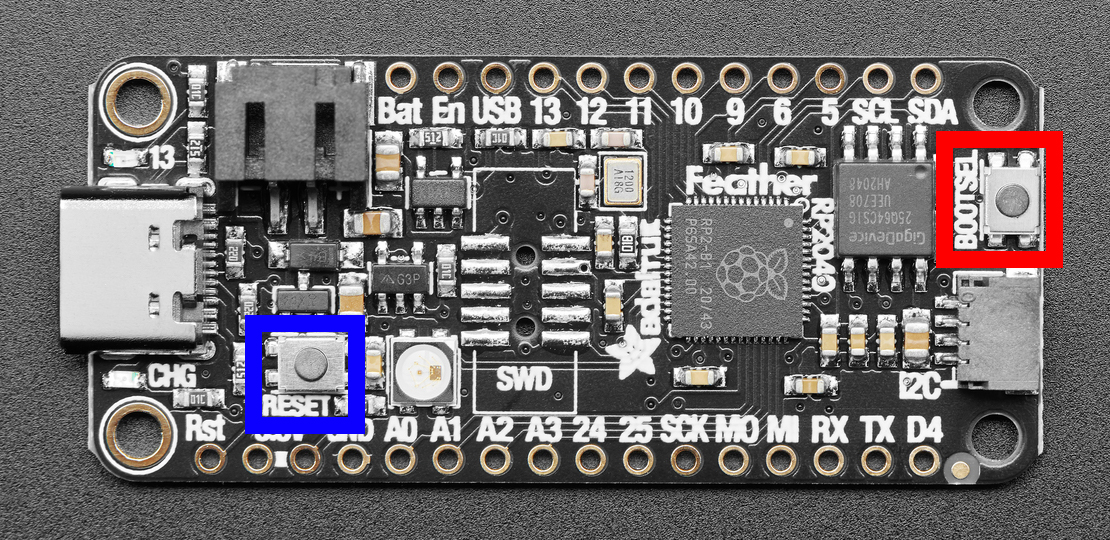
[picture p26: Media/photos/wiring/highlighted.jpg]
button


3. To enter the bootloader, hold down BOOTSEL (highlighted in `red` above), and while continuing to hold it (**`don't let go!`**), press and release the reset button (highlighted in `blue` above). Continue to hold the BOOT/BOOTSEL button until the `RPI-RP2` drive appears!
4. Drag the `.uf2` onto it — the Feather reboots and `CIRCUITPY` appears
5. Copy the firmware files onto `CIRCUITPY`:

```
CIRCUITPY/
├── boot.py
├── code.py
└── lib/
    └── adafruit_hid/
        └── gamepad.py
```

The D13 LED should stay **`blinking`** after reboot. **blinking** = running. **Solid** = error.

---

## Step 4 — Install RetroPie

1. Download the [Raspberry Pi Imager](https://circuitpython.org/board/adafruit_feather_rp2040/) and flash Raspberry Pi OS (64-bit) onto your microSD card.
2. put the cooler onto the raspberry 5 and screw the Raspberry onto the UPS shield
3. 
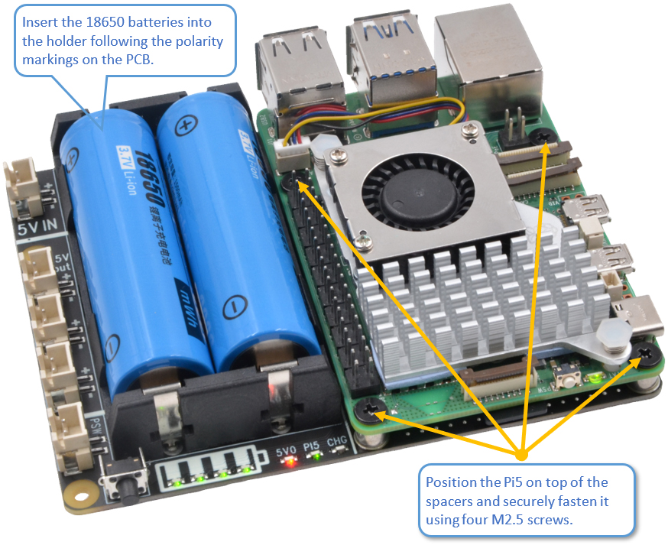
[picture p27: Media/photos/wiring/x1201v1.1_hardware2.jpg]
ups


>[!NOTE]
>Don't inset the batteries just yet

4. Insert the card, connect your monitor, and plug the USB-C power cable into the UPS shield connector. 

> **`don't`** plug it into the Pi 5's own USB-C port

5. After you have everything ready boot into Raspbian and follow this [guide](https://www.youtube.com/watch?v=AaseHnf0k2o), to set up Raspbian and RetroPie on top of it

Watch the video (https://www.youtube.com/watch?v=AaseHnf0k2o)

---

## Step 5 — Load the Games

Download the Roms(games) and continue watching the [guide](https://www.youtube.com/watch?v=AaseHnf0k2o) from 10:15 to add the Roms to the Retropie. 

---

# Step 6 — Set Up the Audio

See the [Wiring Guide](wiring_guide.md) for the full audio schematic and connection tables.

The Pi 5 has no headphone jack, so the PCM5122 DAC is required to convert the digital I2S signal to analog audio. Wire the DAC to the Pi over I2S and I2C (8 wires total), connect the DAC outputs to the PAM8403 inputs, and the amp outputs to the speakers. Make sure MOD2 is pulled to 3.3V.

### Configure the Pi

```
sudo nano /boot/firmware/config.txt
```

Find or add these lines:

```
dtparam=i2c_arm=on        <- Add this line
# dtparam=i2s=on          <- Comment this out or remove it entirely
dtparam=audio=off         <- Disable onboard audio
```

add the DAC overlay at the bottom of the file :

```
dtoverlay=iqaudio-dac
```

> [!IMPORTANT]
> Do **not** leave `dtparam=i2s=on` enabled. RetroPie adds this line, and it causes the kernel to claim GPIO18 (the I2S bit clock) before the `iqaudio-dac` overlay can use it. The DAC will appear in `aplay -l` and respond on I2C, but no audio will actually reach it. Commenting out `dtparam=i2s=on` and letting the overlay manage I2S on its own is the fix.

After rebooting, verify the DAC is detected:

```
aplay -l                         # Should show: card 2: IQaudIODAC
play something on youtube        # Should hear something from both speakers
```

### Make the Config Survive Reboots

RetroPie overwrites the ALSA config on every boot. To prevent this, write the ALSA configuration into the root-level system files where RetroPie can't touch it:

```
sudo nano /etc/alsa/config.txt/bigtendo.conf
```

```
defaults.pcm.card 2
defaults.ctl.card 2
```

This makes the DAC the default audio device system-wide and survives RetroPie reboots.

### If It Doesn't Work

- **No DAC in `aplay -l`:** Run `sudo i2cdetect -y 1` - look for address `4c`.
- **GPIO18 conflict:** Run `dmesg | grep -i i2s` - if you see a conflict, `dtparam=i2s=on` is still enabled. Comment it out.
- **Audio works in Raspbian but not in EmulationStation or games:** The ALSA root-level config above fixes this.

---

## Step 7 — Solder Buttons and Joysticks

See the [Wiring Guide](wiring_guide.md) for the full pin tables.

Each button connects between one Feather GPIO pin and GND, with the internal pull-up resistor enabled in firmware. Getting buttons to sit in exactly the right spots on the perfboard, so they line up with the holes in the 3D-printed enclosure, is the hardest part of the whole assembly.

The technique that worked for me:

1. Tape the button caps tightly in place on the upper shell
2. Put buttons into the caps

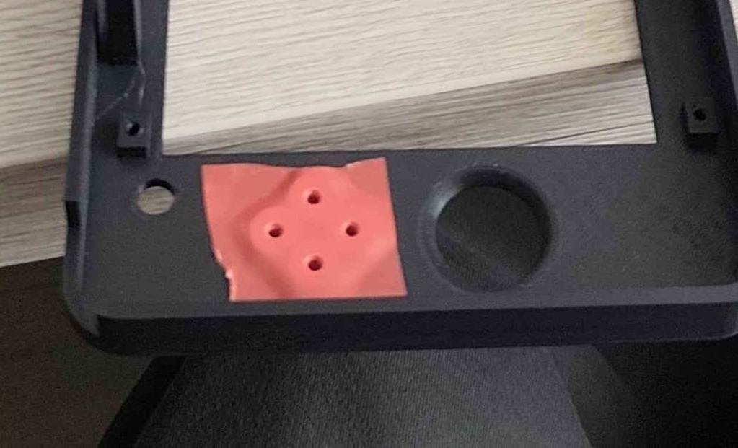
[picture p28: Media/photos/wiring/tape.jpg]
tape


3. Place the upper shell onto the lower half so the buttons touch the perfboard
4. Press the buttons down gently
5. Lift the shell carefully without shifting anything 
6. Mark where their pins land on the perfboard and solder the buttons at those positions
7. Test fit before moving on to the next set

Repeat this for each button. Shoulder buttons don't need precise positioning - they are hot-glued to their pillar anyway, so just solder them wherever they reach and glue them in place.

Each joystick has 5 wires: VCC (3.3V), GND, VRx, VRy, and SW (click). Screw the joysticks into their pillars before soldering the wires. The right joystick is mounted 90° clockwise in the enclosure - don't try to compensate it in wiring, the firmware handles it with `SWAP_JOY1_XY = True` and `INVERT_JOY1_X = True`.

| | |
|:--:|:--:|
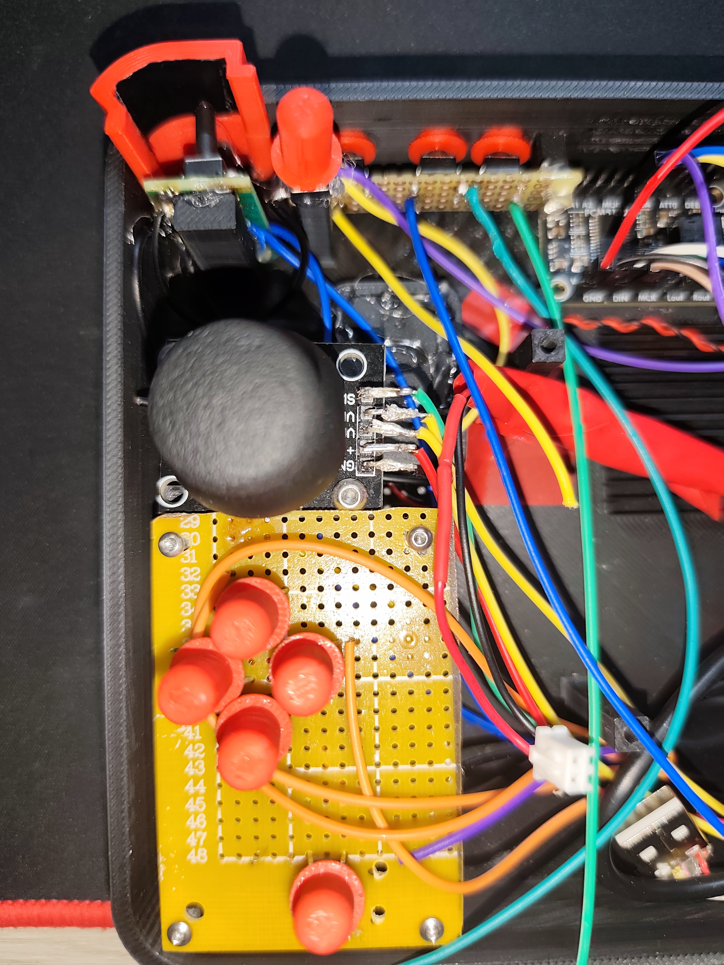
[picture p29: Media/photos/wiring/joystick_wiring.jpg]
joystick wiring
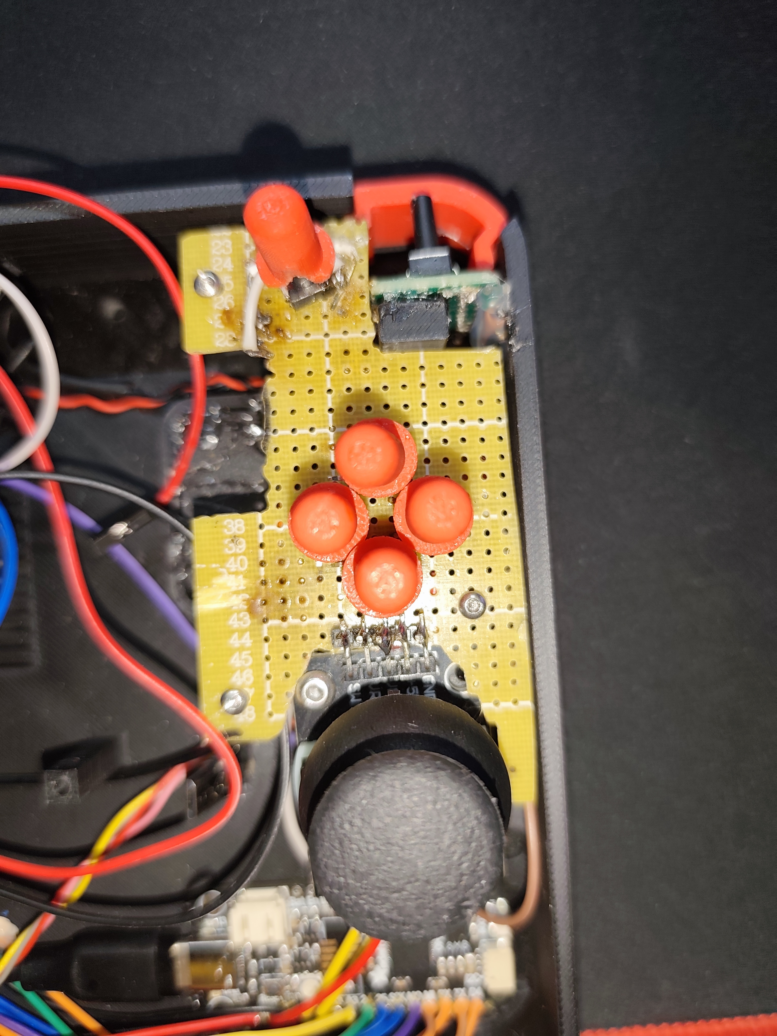
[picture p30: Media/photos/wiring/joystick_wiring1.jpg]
joystick wiring
|  | 

To verify, plug it into any PC and open [hardwaretester.com](https://hardwaretester.com/gamepad) - all 17 buttons and both joystick axes should register.

---

## Step 8 — Final Assembly

### Bottom shell (install in this order)

1. 18650 cells into the battery holders

> [!WARNING]
> Double-check battery polarity before connecting. Reversed polarity can permanently damage the Pi and the UPS shield.

2. PCM5122 DAC and PAM8403 amp into their mounts
3. Speakers on top of the honeycomb grilles
4. screw perfboards and joysticks in position
5. Route all wires flat — pinched wires are the main reason the case won't close

### Top shell

1. Display in its cutout, DSI ribbon cable connected to the Pi
2. Button caps through the shell holes

> [!TIP]
> Tape the back of the UPS shield with electric tape, just to be sage.

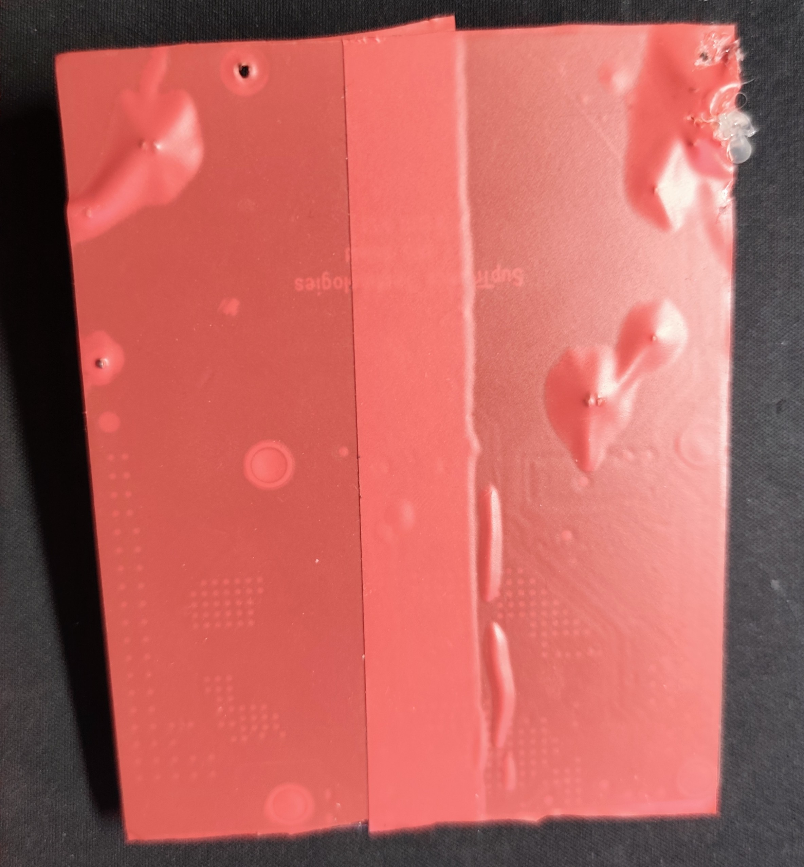
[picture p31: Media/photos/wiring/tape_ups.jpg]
tape


### Close it up

Connect the HDMI ribbon, Feather USB cable, and all remaining wires. Align the two halves and press them together. Screw the 2 halves together. Power on and START PLAYING!

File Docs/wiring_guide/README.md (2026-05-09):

# Wiring Guide

Every wire connection in the Bigtendo console.

## Feather RP2040

Solder all the jumper wires exactly like in the table below - the result should look like the image.

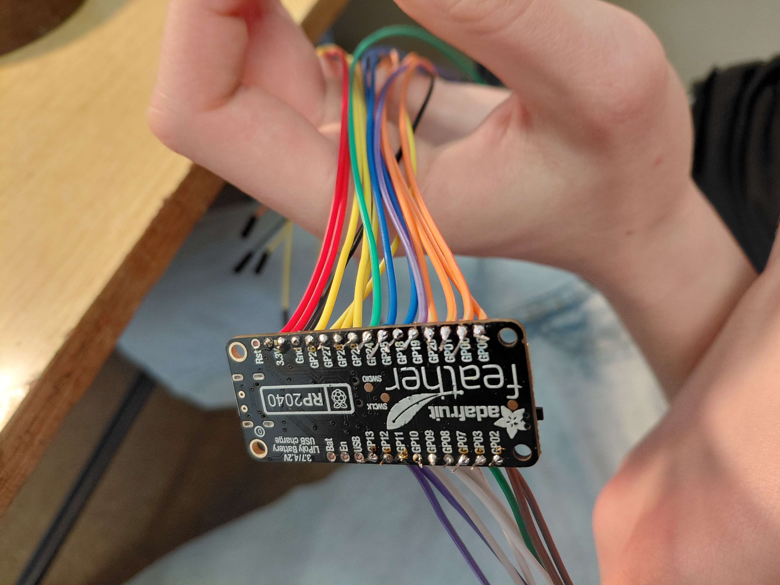
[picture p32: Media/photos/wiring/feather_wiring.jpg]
Feather wiring


| Feather Pins | Wire Color |
|---|---|
| `board.D12` \| `board.D13` \| `board.MOSI` | Purple |
| `board.D11` \| `board.D10` \| `board.D9` \| `board.D6` | White |
| `board.D5` \| `board.D24` | Green |
| `board.SDA` \| `board.SCL` | Brown |
| 3.3V | Red |
| GND | Black |
| `board.A0` \| `board.A1` \| `board.A2` \| `board.A3` | Yellow |
| `board.D25` \| `board.SCK` | Blue |
| `board.MISO` \| `board.RX` \| `board.TX` \| `board.D4` | Orange |

## Buttons

All buttons use the Feather's internal pull-up resistors. One leg connects to the Feather GPIO pin, the other to GND.

### Button Pin Assignments

| Physical Button | CircuitPython Pin | Wire Color |
|---|---|---|
| Left Joystick Click | `board.D5` | Green |
| A | `board.D6` | White |
| B | `board.D9` | White |
| X | `board.D10` | White |
| Y | `board.D11` | White |
| Start | `board.D12` | Purple |
| Select | `board.D13` | Purple |
| Right Joystick Click | `board.D24` | Green |
| Left Trigger (lower) | `board.D25` | Blue |
| Left Trigger (upper) | `board.SCK` | Blue |
| Home | `board.MOSI` | Purple |
| Arrow Down | `board.MISO` | Orange |
| Arrow Up | `board.RX` | Orange |
| Arrow Right | `board.TX` | Orange |
| Right Trigger (upper) | `board.SDA` | Brown |
| Right Trigger (lower) | `board.SCL` | Brown |
| Arrow Left | `board.D4` | Orange |

## Joysticks

Each joystick has 5 pins: VCC (3.3V), GND, VRx (analog X), VRy (analog Y), and SW (click button).

### Right Joystick

| Joystick Pin | Feather Pin | Wire Color |
|---|---|---|
| VRy | `board.A0` | Yellow |
| VRx | `board.A1` | Yellow |
| SW (button) | `board.D5` | Green |
| VCC | 3.3V | Red |
| GND | GND | Black |

### Left Joystick

| Joystick Pin | Feather Pin | Wire Color |
|---|---|---|
| VRy | `board.A2` | Yellow |
| VRx | `board.A3` | Yellow |
| SW (button) | `board.D24` | Green |
| VCC | 3.3V | Red |
| GND | GND | Black |

## Audio Schematic

**Signal path:** Pi 5 -> PCM5122 I2S DAC -> PAM8403 Stereo Class D Amplifier -> Speakers

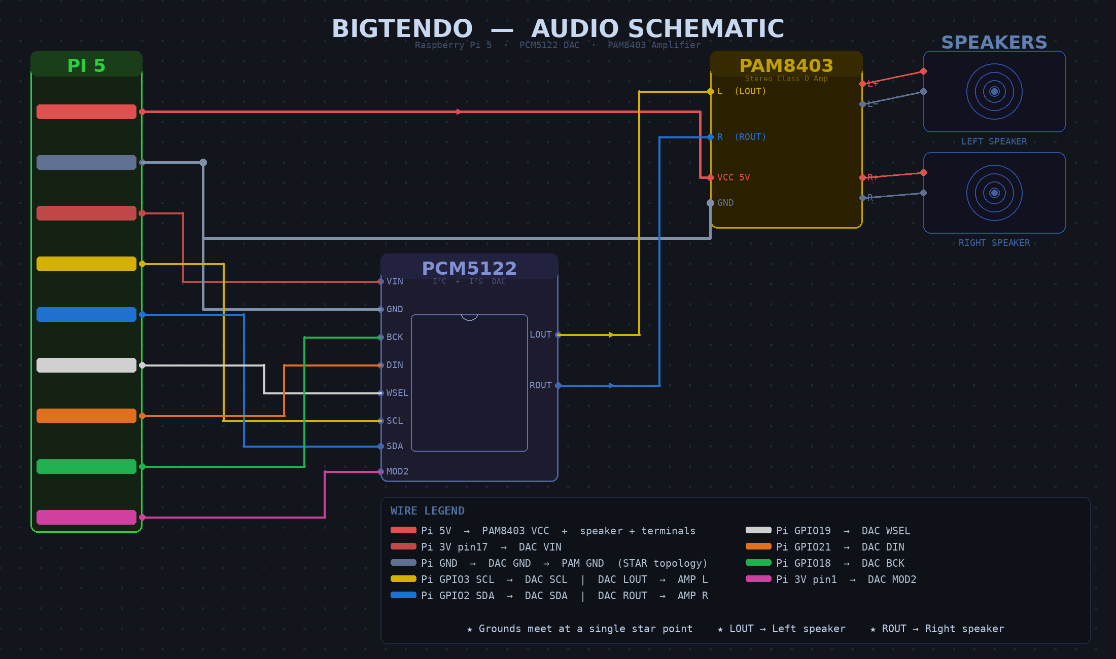
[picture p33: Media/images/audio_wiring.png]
Audio Schematic


### Pi 5 -> PCM5122 DAC

| Pi 5 Pin | PCM5122 Pin | Wire Color | Purpose |
|---|---|---|---|
| 3V (Pin 17) | VIN | Pink/Red | DAC power |
| GND | GND | Grey | Ground  |
| GPIO18 (Pin 12) | BCK | Green | I2S bit clock |
| GPIO19 (Pin 35) | WSEL | Grey/White | I2S word select |
| GPIO21 (Pin 40) | DIN | Orange | I2S audio data |
| GPIO3 / SCL (Pin 5) | SCL | Yellow | I2C clock |
| GPIO2 / SDA (Pin 3) | SDA | Blue | I2C data |
| 3V (Pin 1) | MOD2 | Pink | Enables I2C control mode |

### PCM5122 DAC → PAM8403 Amplifier

| PCM5122 Output | PAM8403 Input |
|---|---|
| LOUT | L (left channel audio in) |
| GND | GND |
| ROUT | R (right channel audio in) |

### PAM8403 Amplifier - Power

| Source | PAM8403 Pin |
|---|---|
| Pi 5V | VCC 5V |
| Pi GND | GND |

### PAM8403 Amplifier -> Speakers

| PAM8403 Output | Speaker |
|---|---|
| L+ / L- | Left 2030 cavity speaker (8Ω, 2W) |
| R+ / R- | Right 2030 cavity speaker (8Ω, 2W) |

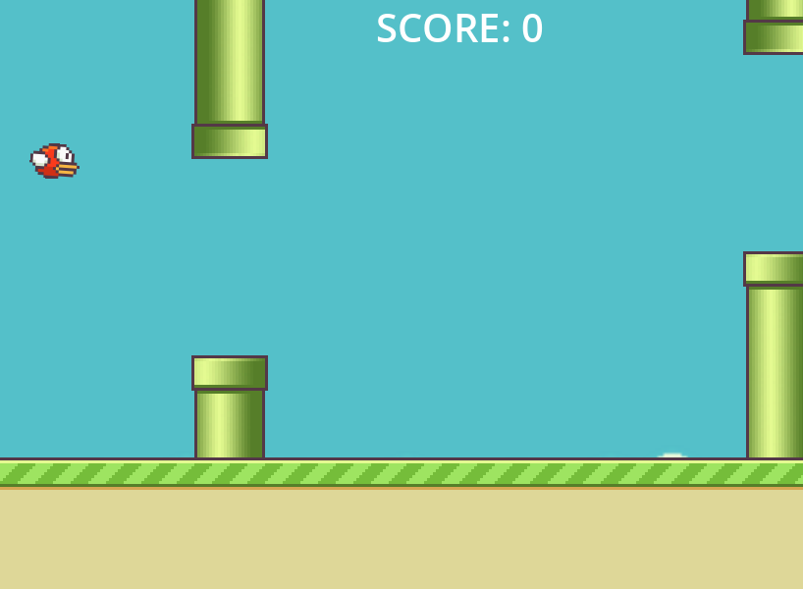
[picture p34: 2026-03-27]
Media/photos/wiring/flappybird.png

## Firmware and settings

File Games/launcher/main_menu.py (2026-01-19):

# """
# Main Menu - Standalone Launcher
# Single controller navigation
#  """
# Pong can still have AI opponent - single player vs computer
# No multiplayer games - all single player
# Controller mapping - Only Controller 1 GPIO pins (17-26)
# Menu navigation - UP/DOWN/A/B only
# RetroPie integration - Works with single controller
# urobit potom, standalone menu
# import pygame
# import sys
# import os

# # Add parent to path
# sys.path.insert(0, os.path.join(os.path.dirname(__file__), '..'))

# from shared.config import *
# from shared.gpio_handler import input_handler
# from shared.save_system import save_system

# # Import all games
# from games.Pygame.snake.snake import SnakeGame
# from games.Pygame.pong.pong import PongGame
# from games.Pygame.memory.memory import MemoryGame
# from games.Pygame.breakout.breakout import BreakoutGame
# from games.Pygame.space_invaders.invaders import SpaceInvadersGame
# from games.Pygame.tetris.tetris import TetrisGame

# pygame.init()
# screen = pygame.display.set_mode((SCREEN_WIDTH, SCREEN_HEIGHT), pygame.FULLSCREEN)
# clock = pygame.time.Clock()

# # Game list
# games = [
#     {"name": "Snake", "class": SnakeGame, "engine": "Pygame"},
#     {"name": "Tetris", "class": TetrisGame, "engine": "Pygame"},
#     {"name": "Pong", "class": PongGame, "engine": "Pygame"},
#     {"name": "Breakout", "class": BreakoutGame, "engine": "Pygame"},
#     {"name": "Space Invaders", "class": SpaceInvadersGame, "engine": "Pygame"},
#     {"name": "Memory", "class": MemoryGame, "engine": "Pygame"},
#     {"name": "Settings", "class": None, "engine": None},
#     {"name": "Exit", "class": None, "engine": None}
# ]

# selected = 0
# show_scores = False

# # Fonts
# font_title = pygame.font.Font(None, 96)
# font_game = pygame.font.Font(None, 60)
# font_small = pygame.font.Font(None, 36)
# font_tiny = pygame.font.Font(None, 24)

# def draw_menu():
#     screen.fill(BLACK)
    
#     # Title
#     title = font_title.render("RETRO CUBE", True, NINTENDO_RED)
#     title_rect = title.get_rect(center=(SCREEN_WIDTH // 2, 60))
#     screen.blit(title, title_rect)
    
#     # Subtitle
#     subtitle = font_small.render("Gaming Console", True, WHITE)
#     subtitle_rect = subtitle.get_rect(center=(SCREEN_WIDTH // 2, 120))
#     screen.blit(subtitle, subtitle_rect)
    
#     # Games list
#     start_y = 180
#     spacing = 50
    
#     for i, game in enumerate(games):
#         y = start_y + i * spacing
        
#         # Selection highlight
#         if i == selected:
#             pygame.draw.rect(screen, BLUE, (50, y - 5, 700, 45), 3)
#             color = YELLOW
#         else:
#             color = WHITE
        
#         # Game name
#         text = font_game.render(game["name"], True, color)
#         screen.blit(text, (70, y))
        
#         # High score (if available)
#         if game["class"]:
#             high_score = save_system.get_highscore(game["name"])
#             if high_score > 0:
#                 score_text = font_small.render(f"Best: {high_score}", True, GRAY)
#                 screen.blit(score_text, (500, y + 5))
        
#         # Engine badge
#         if game["engine"]:
#             engine_text = font_tiny.render(game["engine"], True, DARK_GREEN)
#             screen.blit(engine_text, (650, y + 10))
    
#     # Instructions
#     inst = font_small.render("UP/DOWN: Navigate  |  A: Select  |  B: Exit", True, GREEN)
#     inst_rect = inst.get_rect(center=(SCREEN_WIDTH // 2, SCREEN_HEIGHT - 30))
#     screen.blit(inst, inst_rect)
    
#     pygame.display.flip()

# def handle_input():
#     global selected, show_scores
    
#     keys = pygame.key.get_pressed()
    
#     # Navigate up
#     if keys[pygame.K_UP] or input_handler.is_pressed('UP'):
#         selected = (selected - 1) % len(games)
#         pygame.time.wait(200)
    
#     # Navigate down
#     if keys[pygame.K_DOWN] or input_handler.is_pressed('DOWN'):
#         selected = (selected + 1) % len(games)
#         pygame.time.wait(200)
    
#     # Select
#     if keys[pygame.K_RETURN] or keys[pygame.K_SPACE] or input_handler.is_pressed('A'):
#         return execute_selection()
    
#     # Exit
#     if keys[pygame.K_ESCAPE] or keys[pygame.K_b] or input_handler.is_pressed('B'):
#         return False
    
#     return True

# def execute_selection():
#     global selected
    
#     game = games[selected]
    
#     if game["name"] == "Exit":
#         return False
    
#     elif game["name"] == "Settings":
#         show_settings()
#         return True
    
#     elif game["class"]:
#         # Launch game
#         try:
#             game_instance = game["class"](screen, fullscreen=False)
#             final_score = game_instance.run()
            
#             # Update high score
#             if final_score > 0:
#                 is_record = save_system.update_score(game["name"], final_score)
#                 if is_record:
#                     show_new_record(game["name"], final_score)
        
#         except Exception as e:
#             print(f"Error launching {game['name']}: {e}")
#             show_error(game["name"], str(e))
        
#         return True
    
#     return True

# def show_settings():
#     """Settings screen"""
#     running = True
#     setting_selected = 0
#     settings = [
#         "Sound: ON",
#         "Display: 800x480",
#         "Controller Test",
#         "About",
#         "Back"
#     ]
    
#     while running:
#         screen.fill(BLACK)
        
#         # Title
#         title = font_title.render("SETTINGS", True, NINTENDO_RED)
#         title_rect = title.get_rect(center=(SCREEN_WIDTH // 2, 80))
#         screen.blit(title, title_rect)
        
#         # Settings list
#         start_y = 180
#         for i, setting in enumerate(settings):
#             y = start_y + i * 60
            
#             if i == setting_selected:
#                 pygame.draw.rect(screen, BLUE, (100, y - 5, 600, 50), 3)
#                 color = YELLOW
#             else:
#                 color = WHITE
            
#             text = font_game.render(setting, True, color)
#             screen.blit(text, (120, y))
        
#         # Instructions
#         inst = font_small.render("UP/DOWN: Navigate  |  A: Select  |  B: Back", True, GREEN)
#         inst_rect = inst.get_rect(center=(SCREEN_WIDTH // 2, SCREEN_HEIGHT - 30))
#         screen.blit(inst, inst_rect)
        
#         pygame.display.flip()
        
#         # Input
#         for event in pygame.event.get():
#             if event.type == pygame.QUIT:
#                 running = False
#             if event.type == pygame.KEYDOWN:
#                 if event.key == pygame.K_UP:
#                     setting_selected = (setting_selected - 1) % len(settings)
#                 elif event.key == pygame.K_DOWN:
#                     setting_selected = (setting_selected + 1) % len(settings)
#                 elif event.key == pygame.K_RETURN or event.key == pygame.K_SPACE:
#                     if settings[setting_selected] == "Back":
#                         running = False
#                     elif settings[setting_selected] == "Controller Test":
#                         show_controller_test()
#                     elif settings[setting_selected] == "About":
#                         show_about()
#                 elif event.key == pygame.K_ESCAPE or event.key == pygame.K_b:
#                     running = False
        
#         clock.tick(FPS)

# def show_controller_test():
#     """Test controller buttons"""
#     running = True
    
#     while running:
#         screen.fill(BLACK)
        
#         title = font_title.render("CONTROLLER TEST", True, NINTENDO_RED)
#         title_rect = title.get_rect(center=(SCREEN_WIDTH // 2, 50))
#         screen.blit(title, title_rect)
        
#         # Instructions
#         inst = font_small.render("Press buttons to test", True, WHITE)
#         inst_rect = inst.get_rect(center=(SCREEN_WIDTH // 2, 120))
#         screen.blit(inst, inst_rect)
        
#         # Button status
#         buttons = ['UP', 'DOWN', 'LEFT', 'RIGHT', 'A', 'B', 'START', 'SELECT']
#         y = 180
        
#         for button in buttons:
#             is_pressed = input_handler.is_pressed(button)
#             color = GREEN if is_pressed else GRAY
#             text = font_game.render(f"{button}: {'PRESSED' if is_pressed else 'Released'}", True, color)
#             screen.blit(text, (150, y))
#             y += 50
        
#         # Back instruction
#         back = font_small.render("Press B to go back", True, GREEN)
#         back_rect = back.get_rect(center=(SCREEN_WIDTH // 2, SCREEN_HEIGHT - 30))
#         screen.blit(back, back_rect)
        
#         pygame.display.flip()
        
#         # Check for exit
#         keys = pygame.key.get_pressed()
#         if keys[pygame.K_b] or keys[pygame.K_ESCAPE] or input_handler.is_pressed('B'):
#             running = False
        
#         clock.tick(FPS)

# def show_about():
#     """About screen"""
#     running = True
    
#     while running:
#         screen.fill(BLACK)
        
#         title = font_title.render("ABOUT", True, NINTENDO_RED)
#         title_rect = title.get_rect(center=(SCREEN_WIDTH // 2, 60))
#         screen.blit(title, title_rect)
        
#         # Info
#         info_lines = [
#             "Retro Cube Console",
#             "Hellathon 2025",
#             "",
#             "Hardware:",
#             "- Raspberry Pi 5",
#             "- 7\" Display",
#             "- Custom Controller",
#             "",
#             "Software:",
#             "- Pygame Games",
#             "- Custom Launcher",
#             "",
#             "Team: [Your Team Name]"
#         ]
        
#         y = 140
#         for line in info_lines:
#             text = font_small.render(line, True, WHITE)
#             text_rect = text.get_rect(center=(SCREEN_WIDTH // 2, y))
#             screen.blit(text, text_rect)
#             y += 35
        
#         # Back
#         back = font_small.render("Press B to go back", True, GREEN)
#         back_rect = back.get_rect(center=(SCREEN_WIDTH // 2, SCREEN_HEIGHT - 30))
#         screen.blit(back, back_rect)
        
#         pygame.display.flip()
        
#         # Check exit
#         keys = pygame.key.get_pressed()
#         if keys[pygame.K_b] or keys[pygame.K_ESCAPE] or input_handler.is_pressed('B'):
#             running = False
        
#         clock.tick(FPS)

# def show_new_record(game_name, score):
#     """Show new high score screen"""
#     screen.fill(BLACK)
    
#     title = font_title.render("NEW RECORD!", True, YELLOW)
#     title_rect = title.get_rect(center=(SCREEN_WIDTH // 2, 150))
#     screen.blit(title, title_rect)
    
#     game_text = font_game.render(game_name, True, WHITE)
#     game_rect = game_text.get_rect(center=(SCREEN_WIDTH // 2, 240))
#     screen.blit(game_text, game_rect)
    
#     score_text = font_game.render(f"Score: {score}", True, GREEN)
#     score_rect = score_text.get_rect(center=(SCREEN_WIDTH // 2, 310))
#     screen.blit(score_text, score_rect)
    
#     pygame.display.flip()
#     pygame.time.wait(3000)

# def show_error(game_name, error):
#     """Show error screen"""
#     screen.fill(BLACK)
    
#     title = font_title.render("ERROR", True, RED)
#     title_rect = title.get_rect(center=(SCREEN_WIDTH // 2, 150))
#     screen.blit(title, title_rect)
    
#     game_text = font_game.render(f"Game: {game_name}", True, WHITE)
#     game_rect = game_text.get_rect(center=(SCREEN_WIDTH // 2, 240))
#     screen.blit(game_text, game_rect)
    
#     error_text = font_small.render(f"Error: {error[:40]}", True, RED)
#     error_rect = error_text.get_rect(center=(SCREEN_WIDTH // 2, 310))
#     screen.blit(error_text, error_rect)
    
#     pygame.display.flip()
#     pygame.time.wait(3000)

# # Main loop
# running = True
# while running:
#     for event in pygame.event.get():
#         if event.type == pygame.QUIT:
#             running = False
    
#     draw_menu()
#     running = handle_input()
#     clock.tick(FPS)

# pygame.quit()
# input_handler.cleanup()
# sys.exit()

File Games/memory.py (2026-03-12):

import pygame
import random
import time
from pygames_modules import *
from pygames_modules import Game


class Card:
    def __init__(self, x, y, card_type, card_id, width=100, height=100):
        self.x = x
        self.y = y
        self.card_type = card_type  
        self.card_id = card_id  
        self.is_flipped = False  
        self.is_matched = False  
        self.flip_progress = 0.0  
        
        self.width = width
        self.height = height
        
        self.rect = pygame.Rect(self.x, self.y, self.width, self.height)

        front_img = pygame.image.load(f"Games/assets/images/memory/{card_type}.png")
        self.front_surf = pygame.transform.scale(front_img, (self.width, self.height))
        
        back_img = pygame.image.load("Games/assets/images/memory/card_back.png")
        self.back_surf = pygame.transform.scale(back_img, (self.width, self.height))
    
    def update(self, dt):
        if self.is_flipped and self.flip_progress < 1.0:
            self.flip_progress += dt * 4 
            if self.flip_progress > 1.0:
                self.flip_progress = 1.0
        
        elif not self.is_flipped and self.flip_progress > 0.0:
            self.flip_progress -= dt * 4
            if self.flip_progress < 0.0:
                self.flip_progress = 0.0
    
    def draw(self, screen, selected=False):
        if self.is_matched:
            return
        
        scale = abs(self.flip_progress - 0.5) * 2  
        current_width = int(self.width * scale)
        
        if self.flip_progress > 0.5:
            surf = self.front_surf
        else:
            surf = self.back_surf
        
        if current_width > 0:
            scaled_surf = pygame.transform.scale(surf, (current_width, self.height))
            x_offset = (self.width - current_width) // 2
            screen.blit(scaled_surf, (self.x + x_offset, self.y))
        
        if selected and not self.is_matched:
            pygame.draw.rect(screen, "yellow", self.rect, 4)
        
        pygame.draw.rect(screen, "white", self.rect, 2)
    
    def flip(self):
        if not self.is_matched:
            self.is_flipped = True
    
    def unflip(self):
        if not self.is_matched:
            self.is_flipped = False


class Memory(Game):
    def __init__(self, fullscreen=True, difficulty="easy"):
        super().__init__(
            fullscreen, 
            icon_path="Games/assets/images/memory/memory_icon.png",
            title="Memory", 
            game_name="Memory"
        )
        
        self.width = pygame.display.get_window_size()[0]
        self.height = pygame.display.get_window_size()[1]
        self.center_x = self.width / 2
        self.center_y = self.height / 2
        
        self.difficulty = difficulty
        if difficulty == "easy":
            self.grid_rows = 4
            self.grid_cols = 4
            self.card_width = 100
            self.card_height = 100
            self.card_spacing = 20
        else:  
            self.grid_rows = 6
            self.grid_cols = 6
            self.card_width = 70
            self.card_height = 70
            self.card_spacing = 15
        
        self.total_pairs = (self.grid_rows * self.grid_cols) // 2
        
        self.card_types = [
            "apple", "banana", "cherry", "grape",
            "orange", "strawberry", "watermelon", "pineapple"
        ]
        
        if difficulty == "hard":
            self.card_types += [
                "kiwi", "mango", "peach", "pear",
                "plum", "lemon", "blueberry", "raspberry",
                "lime", "coconut"
            ]
        
        # 0=difficulty select, 1=game menu, 2=playing, 3=win
        self.game_state = 0
        self.moves = 0
        self.matches_found = 0
        self.start_time = 0
        self.elapsed_time = 0
        
        self.selected_difficulty = 0
        
        self.cursor_row = 0
        self.cursor_col = 0
        
        self.flipped_cards = []
        self.checking_match = False
        self.check_timer = 0
        
        self.cards = []
        self.create_cards()
        
        self.font_large = pygame.font.Font("Games/assets/fonts/Pixeltype.ttf", 60)
        self.font_medium = pygame.font.Font("Games/assets/fonts/Pixeltype.ttf", 40)
        self.font_small = pygame.font.Font("Games/assets/fonts/Pixeltype.ttf", 30)
        
        bg_img = pygame.image.load("Games/assets/images/memory/memory_bg.png")
        self.bg = pygame.transform.scale(bg_img, (self.width, self.height))
        
        if GPIO_ENABLED:
            self.button = "A"
        else:
            self.button = "SPACE"
        
        pygame.mixer.music.load("Games/assets/sounds/music1.wav")
        pygame.mixer.music.set_volume(0.3)
        pygame.mixer.music.play(-1)  
    
    def create_cards(self):
        self.cards = []
        
        card_pairs = []
        for i in range(self.total_pairs):
            card_type = self.card_types[i % len(self.card_types)]
            card_pairs.append(card_type)
            card_pairs.append(card_type)
        
        random.shuffle(card_pairs)
        
        total_grid_width = self.grid_cols * self.card_width + (self.grid_cols - 1) * self.card_spacing
        total_grid_height = self.grid_rows * self.card_height + (self.grid_rows - 1) * self.card_spacing
        
        start_x = (self.width - total_grid_width) // 2
        start_y = (self.height - total_grid_height) // 2 + 30
        
        card_id = 0
        for row in range(self.grid_rows):
            for col in range(self.grid_cols):
                x = start_x + col * (self.card_width + self.card_spacing)
                y = start_y + row * (self.card_height + self.card_spacing)
                card_type = card_pairs[card_id]
                
                card = Card(x, y, card_type, card_id, self.card_width, self.card_height)
                self.cards.append(card)
                card_id += 1
    
    def get_selected_card(self):
        index = self.cursor_row * self.grid_cols + self.cursor_col
        if 0 <= index < len(self.cards):
            return self.cards[index]
        return None

    def find_nearest_unmatched(self, direction):
        start_row = self.cursor_row
        start_col = self.cursor_col

        row, col = start_row, start_col
        for _ in range(self.grid_rows * self.grid_cols):
            if direction == "UP":
                row = (row - 1) % self.grid_rows
            elif direction == "DOWN":
                row = (row + 1) % self.grid_rows
            elif direction == "LEFT":
                col = (col - 1) % self.grid_cols
            elif direction == "RIGHT":
                col = (col + 1) % self.grid_cols

            index = row * self.grid_cols + col
            card = self.cards[index]
            if not card.is_matched:
                self.cursor_row = row
                self.cursor_col = col
                return
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

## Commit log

2026-01-19 Add initial project files and documentation
    Added documentation, design assets, firmware notes, and initial game framework including Python games, Godot project structure, and launcher scripts. Included images, 3D model, and configuration file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
2026-01-19 Update README with project roadmap information
    Added project roadmap details for PCB design.
2026-01-20 Add CircuitPython gamepad firmware and clean up files
    Added new CircuitPython firmware for a custom USB HID gamepad, including boot.py, code.py, and configuration files. Removed obsolete 'feather_code' and added placeholder and system files for the firm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
2026-01-20 Restructure and expand documentation for assembly guides
    Moved and renamed documentation files to organize guides for PCB schematics, build, and wiring. Added new README files with detailed Bigtendo assembly instructions. Relocated related images to wiring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
2026-01-20 Add tip section for ongoing work in assembly guide
    Added a tip section to the assembly guide indicating that work is in progress.
2026-01-20 Update build guide with images and video link
    Added chuck.jpg and wiring diagram references to the build guide README. Included a video thumbnail link for RetroPie setup on Raspberry Pi 5 and clarified firmware upload instructions.
2026-01-21 Move wiring guide images to Media/images directory
    Renamed and relocated Rpi5_pinout.png, audio_wiring.png, audio_wiring_text.png, and feather_pinout.png from Docs/wiring_guide to Media/images for better organization of image assets.
2026-01-22 Add CircuitPython gamepad firmware and documentation
    Updated CircuitPython firmware Updated README.md with usage instructions. Added placeholder and system files for completeness.
2026-03-05 added bom.csv
    [BOM.csv]
2026-03-29 Add STEP and 3MF models; remove STL exports
    Add native CAD and printable 3MF assets and remove older STL exports. New files: Design/3D_Models/.step/{Buttons.step,case_lower.step,case_upper.step} and Design/3D_Models/.3mf_for_printing/{buttons_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
    [Buttons.step, Buttons.stl, buttons_final.3mf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]
2026-03-30 Add game assets and reorganize media
    Add a large set of game assets (images and sounds) for Breakout, Pong, Memory, Snake, Space Invaders and Tetris under Design/Assets and Games/assets, including icons, sprites, backgrounds and multiple audio files. Rename/move various existing media files (Pong sprites, photos moved into Media/photos/wiring, audio_wiring image rename) and relocate a .gitkeep to Games/assets/sounds/. Remove obsolete files: Games/README.md, several Godot .gitkeep placeholders, and an unused schematics image. Also replace/update breakout icon in Design/Assets/images/icons and delete the old backgrounds/breakout_bg.png.
2026-03-30 Rewrite README, add wiring photos, rename image
    Rewrite README.md to provide a more detailed project overview, hardware summary, usage instructions, photos, repository structure, build guide links, contributors, and license. Replace an existing photo filename (Media/photos/...451c.jpg -> Media/photos/case.jpg) and add three new wiring images under Media/photos/wiring (mega.jpg, mega2.jpg, mega3.jpg). These updates improve documentation clarity, add visual references for wiring and assembly, and reorganize the README to better guide builders and developers.
2026-04-26 Add STL models, wiring guide, and photos
    Add exported STL files for buttons and case parts, and rename final .3mf print files for consistency. Replace the wiring guide README with a full, detailed wiring document (Feather pin mappings, button/joystick assignments, and audio schematic). Reorganize and rename wiring-related photos into Media/photos/wiring and add a new print_case.jpg.
    [buttons.3mf, buttons.stl, case_lower.3mf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]
2026-04-26 Revise wiring guide for Feather RP2040 and buttons
    Updated wiring guide for Feather RP2040 and buttons, improving clarity and organization of pin assignments and connections.
2026-05-09 add 3D models, update files, remove folder
    added 3d models of components, updated some files and delete a folder
    [4884 Feather RP2040.step, Adafruit PCM5122 I2S DAC.step, BOM.csv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]
2026-05-17 updated wiring guide
    updated wiring guide
